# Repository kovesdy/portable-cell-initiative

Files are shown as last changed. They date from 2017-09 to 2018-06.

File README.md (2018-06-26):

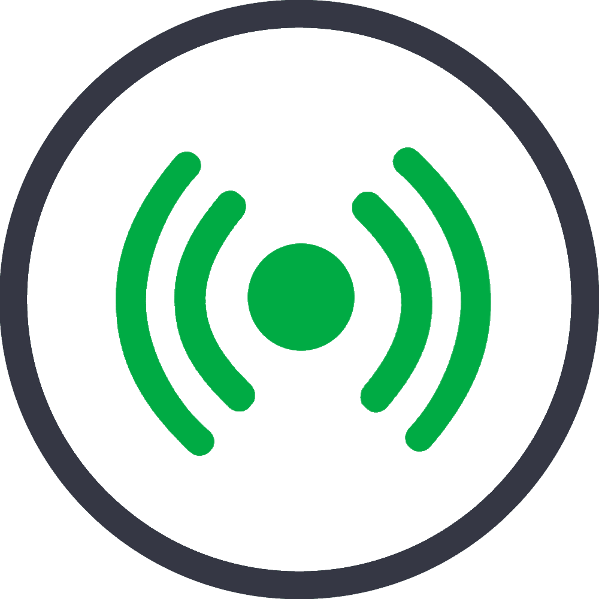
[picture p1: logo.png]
PCI Logo


# Portable Cell Initiative
An open-source software and hardware project to build portable micro-cells for deployment in disaster areas where power, internet, and infrastructure is destroyed.

After several hurricanes earlier this year, Puerto Rico, Houston, and other areas in the United States remain devastated. During and after such tragedies entire communities are left without critical resources, including any way to contact the outside world. Cellular service, a system taken for granted in everyday life, becomes a crucial tool for calling for emergencies, coordinating responses, directing aid, and contacting loved ones. Even regularly working cellular networks can collapse, as when cellular networks were overloaded and temporary paralyzed after the Boston marathon bombing. After natural catastrophes so severe that power lines and cell towers are destroyed, locals may be unable to request assistance, contact family members and friends, and coordinate rebuilding efforts while emergency workers become effectively stranded and unable to communicate for long periods of time.

The “Portable Cell Initiative”, tackles the challenge by developing a small, portable, and light system that acts as a temporary cell tower. These small units, called "microcells" can create a resilient network and be set up with no experience (plug-and-play).

## Features
* Connects to mobile devices through 2G protocol and allows calling, SMS, Internet connection without new SIM cards
* Easy-to-use web portal for mobile users links emergency responders and provides critical information include maps and emergency updates
* Connected to existing satellite constellation infrastructure
* Works anywhere on the planet with no re-configuration
* No dependance on existing infrastructure or power
* Can survive harsh temperature and weather conditions
* Can interconnect with other nearby microcells to create a larger network
* Flexible design
* Cheap and based on open-sourced hardware and software

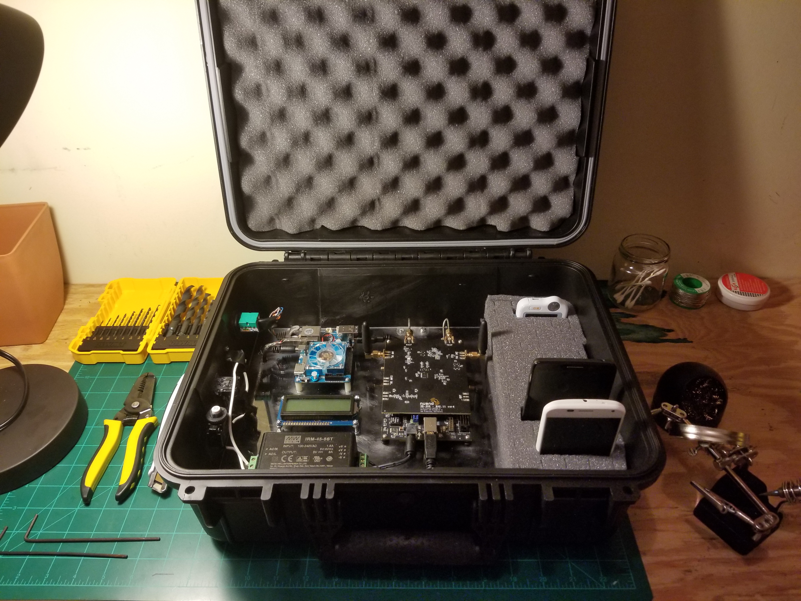
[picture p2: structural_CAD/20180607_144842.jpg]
Beamlink Revision 2 Prototype


## More information

#### [Complete Project Proposal](https://github.com/Ironarcher/portable-cell-initiative/blob/master/documentation/Project%20Proposal.pdf)

### Design and Technical Documents and Schematics
* [CAD Drawings](https://github.com/Ironarcher/portable-cell-initiative/tree/master/structural_CAD)
* [Networking Diagram](https://drive.google.com/file/d/1F7UjbKQFGlt_Ugc90fcQds3FkP_MWMTc/view?usp=sharing)
* [Safety Recommendations](https://github.com/Ironarcher/portable-cell-initiative/raw/master/documentation/Safety%20Recommendations.docx)
* [Properties of the Recommended Antenna](https://github.com/Ironarcher/portable-cell-initiative/raw/master/documentation/Antenna%20Analysis.docx)
* [Circuit Diagram](https://drive.google.com/file/d/19UB1lHhNbGaFvCO_THeIRcXM_tuGDZBh/view?usp=sharing)
* [Antenna Range and Estimation of user capacity](https://github.com/Ironarcher/portable-cell-initiative/raw/master/documentation/Range%20and%20Subscriber%20Analysis.docx)

### Software Development
The Software-defined Radio utilizes OpenBTS and YateBTS to process GSM signals.

The Linux server uses a custom configuration of Ubuntu 14 (Odroid XU4 compatible release). Visit the software page for a README with installation instructions.

#### Additional features available

- Set up instructions to enable config GUI web page and operation with BladeRF radios
- Custom YateBTS configuration files and scripts for disaster relief use
- Firewall configurations to limit idle network usage and connect to the master server
- Integration with Flowroute and its API for international calling
- GPRS configuration for enabling data service
- Automatic phone number assignment to users
- Informational display code (for use with USB serial displays)
- Code for network testing, temperature testing, other procedures

#### Captive Portal
-The Captive Portal technology, a lightweight web application that opens when users first connect to the cell tower, provides quick information to users and a twitter feed of curated information about the situation. This is part of our strategy to reduce network congestion and limit over-use of backhaul resources. Users can always opt to leave the page and access the Internet, returning to the page at any time.

[Find the code and contribute](https://github.com/Ironarcher/beamlink_captiveportal)

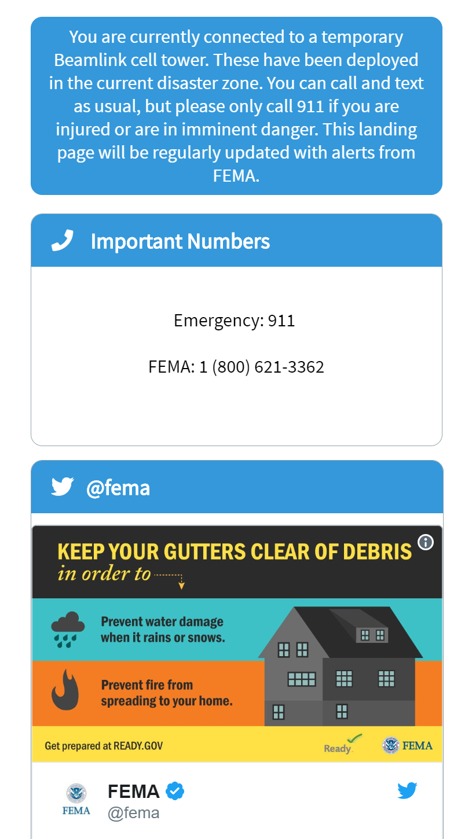
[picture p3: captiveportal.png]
Captive Portal example image


#### In Progress:
- VPN Setup guide between master server and cellular base stations
- Integration with Flowroute SMS API for international texting
- Automatic Flowroute number purchase and number management with OpenBTS
- Switching from GPRS to UMTS data service (3G) based on OpenBTS's UMTS package
- Release of multi-tower communication architecture
- RRLP tracking to allow first responders to locate people in emergency situations based on their cell phone's position (cellular triangulation) - Part of emergency calling as well
- E911 integration (for users to connect to the correct 911 operator in their area)
- Maia: A web service that provides a bird-eye view of our cellular towers connected together, laid on top of Google Maps. View each cell tower's location in proximity to others, and configure their network settings on-the-fly. Have direct access to each tower through built-in SSH capability. Create zones and divide frequencies to reduce cross-tower interference and manage handover settings. Edit automatic phone number systems and receive notifications if the tower malfunctions. Live readouts of pertinent information like core temperatures, number of active connections, new registrations, CPU usage, frequency congestion information, and more.

### Competitions and Challenges
[Mozilla and the National Science Foundation's Wireless Innovation for a Networked Society (Off the Grid Challenge)](https://wirelesschallenge.mozilla.org/#winners) - Honorable Mention

[USC Min Family Social Entrepreneurship Challenge 2017](http://viterbiundergrad.usc.edu/min/) - Finalist

- [People before Profits - USC Viterbi Magazine](https://magazine.viterbi.usc.edu/spring-2018/student-life/people-before-profits/)

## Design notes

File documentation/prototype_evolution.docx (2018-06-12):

Beamlink Prototype Evolution

Beamlink I

A power-efficient, yet powerful single board computer utilizes the newest mobile processors to create an independent cell tower.

The computer can assign phone numbers, store texts, link international calls, host a local web server, and even be remotely monitored and configured.

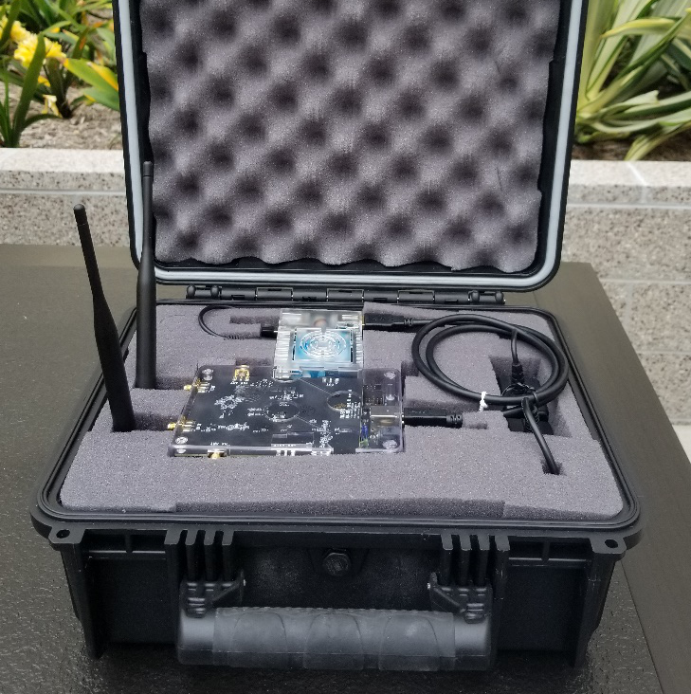
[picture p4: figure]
A picture containing wall, electronics Description generated with high confidence

Integrated battery allows for 7 hours of operation before connecting to outside power.

A water-proof case allows the cell tower to survive even when fully immersed in water. Foam padding and the reinforced case mean that the tower can survive being dropped. And weighing in at 8 pounds, the tower can truly be taken anywhere.

A software-defined radio allows use of any radio protocol, including GSM, Wi-Fi, and even LTE. The system can be instantly configured to meet the regulatory requirements of any country.

Beamlink II

Custom ports allow ethernet and power connections from the outside while keeping out water, while a switch provides more control over the device.

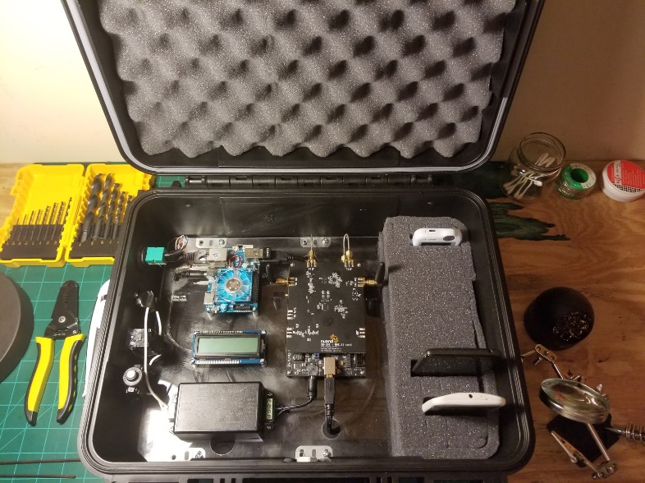
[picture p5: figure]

Built-in antennas and smaller coaxial cables allow for the case to operate while closed, even when an amplifier is attached.

The larger case has space for storing extra, pre-configured phones and medical devices. And the device is even lighter, at 7.5 pounds.

A custom power supply further reduces power consumption to 11.2-11.9 W during cell tower operation.

The information display reads out real-time information, such as the tower’s status, registered phones, and active connections.

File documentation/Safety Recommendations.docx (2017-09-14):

Portable Cell Initiative

Safety Considerations for Microcells

By: Arpad Kovesdy

Radiation and Antenna Safety

1. Electromagnetic radiation emitted by cellular phones and the base station antenna is considered nonionizing radiation: which means that the radiation’s energy is too low to ionize atoms. There are still dangers to using radio equipment, such as thermal effects. These thermal effects can cause injuries because electromagnetic radiation can heat body tissue, especially close to resonant body frequencies, which include 35 MHz, 70 MHz, and 400 MHz for adults, and additional resonances near 700 MHz and 1 GHz.
2. There is some research to suggest a link between biological effects and exposure to radiation. However, there is no demonstrated correlation that “low-level EMR causes adverse health effects”.
3. “The IEEE guidelines excludes any transmitter with an output below 7W because such low-power transmitters would not be able to produce significant whole-body heating”. However, there is concern that certain power densities may be more than standards when considering small transmitters place near the head.

General Guidelines

I. No person should ever be next to a transmitted antenna while it is being powered. Never transmit above 25W in a VHF radio mobile installation without measuring the RF fields emitted in the surrounding area.
II. When using transmitters that transmit above 1 kW of power, ensure that directional antennas are raised 35 feet above inhabited areas.
III. Never work on or touch an RF antenna when power is applied.

Antenna Grounding

1. Only certain types of antennas require grounding[^1], which include ones that require current flow to the ground to complete a circuit. For example, a quarter-wave vertical is one antenna that requires one wire to connect from the feedline to the base of the antenna and one wire that connects to ground.
2. All other antennas do not require a direct connection to ground. These include dipole antennas or ground plane antennas.
3. “Common-mode currents” must be kept off of the feedline through the use of a “current or choke balun”.

General Guidelines

I. Per the specified recommendations to use a half-wave dipole or similar variant with a ground plane, a current or choke balun must be attached.
II. A direct connection to RF ground is not required if using a half-wave dipole or similar variant with a ground plane.

Electrical Grounding

Generator Safety

I. Stay at least 24 inches away from power supply, linear generators, transformers, electrical fans, and other sources or drains of AC power when power is applied to avoid exposure to high-level 60 Hz magnetic fields.

Additional Safe Practices

Reference: The 1997 ARRL Handbook for Radio Amateurs © 1996 American Radio Relay League, Inc. (available for reproduction for noncommercial use, provided credit is given)

[^1] http://www.arrl.org/grounding

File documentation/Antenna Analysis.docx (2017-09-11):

Portable Cell Initiative

Antenna Analysis for Microcells

By: Arpad Kovesdy

Summary

The antenna’s design, provided a 30 m elevation from a real ground, provides an isotropic gain that varies from 6.48 dBi for the downlink antenna to 7.25 dBi for the uplink antenna based on computer models in 4nec2 (a computer program). Radiation patterns modeled support the antenna theory of horizontal omnidirectionality, even in different environments. The antennae standing wave ratios are at a manageable value of 1.18 based on the average operating frequency used and a 50 Ω coaxial cable feed line. Other factors such as feed line attenuation are also explored further.

Basic Antenna Configuration

The microcell’s base station for GSM communications consists of two antennas: one for uplink (handling radio communications the mobile user to the microcell) and one for downlink (microcell to the mobile users). For both antennae, there are two portions: a conducting and a grounding region. In a classic half-wave dipole antenna that is pointing vertically and is thus vertically polarized, the feed point will be at the middle of two conductors pointing towards the ground and towards the sky. The vertical polarization is common in mobile systems because “vertical polarization has somewhat lower attenuation over terrain”[^1].The radiation pattern of this type of antenna is a donut shape that projects most of the radiation perpendicular to the conductor. To lower the impedance to the characteristic impedance of the feed line (which is 50 Ω), from the antenna impedance of a dipole, the grounding portion is raised closer to be 30° below the horizontal. In total, there are three conductors that point out from the center to form the grounding portion to improve omnidirectionality. Here is an image of the projected geometry with wires in gray and axes in green:

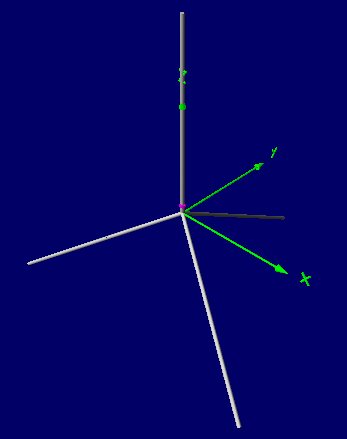
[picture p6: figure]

Antenna Characteristics
The length of the antenna conductors (which is around a quarter of the wavelength of the transmitted or received radio wave since the complete system is based on a half-wave dipole design) is given by the following equation[^2]:

Monopole Length (feet)=234/(Frequency (MHz))

The following characteristics of the antennae were calculated based on simulations in 4nec2, a program for showing how EM radiation is generated by different antenna geometries. The same simulations were also conducted over a 30 m real ground, which offers more realism than the simulation of the antennae in free space (an environment that does not practically exist). The diameter of the wires used in the antennae is 0.81 mm, which is the same size as the core of a common 50 Ω coaxial cable (RG-58 U). The following tables show the various characteristics that were computed using the computer models:

Characteristic | Value
Transmission frequency range | 890 – 915 MHz
Average operating frequency | 902.5 MHz
Wavelength | 0.332 m
Monopole length | 0.07903 m
Number of monopoles | 4
Isotropic Gain in Free Space | 1.77 dBi
Isotropic Gain above a 30 m real ground | 7.25 dBi
Relative Directivity Factor | 9.67
Impedance | 44.1 Ω
Radiated Efficiency (30 m above real ground) | 59.47 %
S.W.R. (50 Ω feed line) | 1.18

Table 1: Uplink Antenna Characteristics

Characteristic | Value
Transmission frequency range | 930 – 960 MHz
Average operating frequency | 945 MHz
Wavelength | 0.317 m
Monopole length | 0.0755 m
Number of monopoles | 4
Isotropic Gain in Free Space | 1.77 dBi
Isotropic Gain above a 30 m real ground | 6.48 dBi
Relative Directivity Factor | 8.74
Impedance | 44.3 Ω
Radiated Efficiency (30 m above real ground) | 59.43%
S.W.R. (50 Ω feed line) | 1.18

Table 2: Downlink Antenna Characteristics

The following images depict the radiation patterns of the uplink antenna (which are very similar for the downlink antenna) in different environments. There are 3D plots which show the area around the antenna and 2D plots which show the patterns from a vertical and horizontal aspect. The first two images are in free space and the second two are when the antenna is 30 m above real ground.

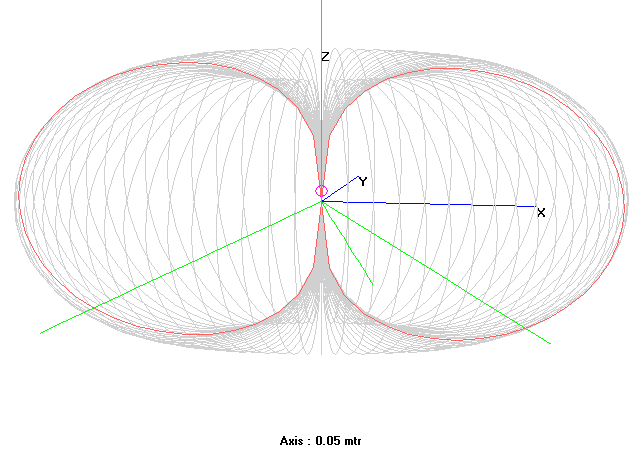
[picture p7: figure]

Image 2: Radiation Pattern (Uplink) in free space

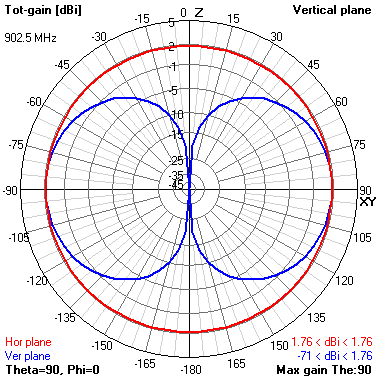
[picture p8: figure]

Image 3: Radiation pattern (uplink) from the vertical plane’s perspective in free space

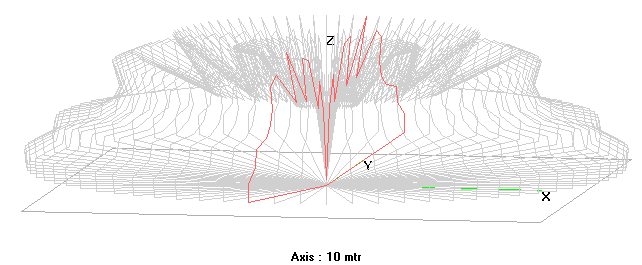
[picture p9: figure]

Image 4: Radiation pattern (uplink) when the antenna is 30 m above real ground

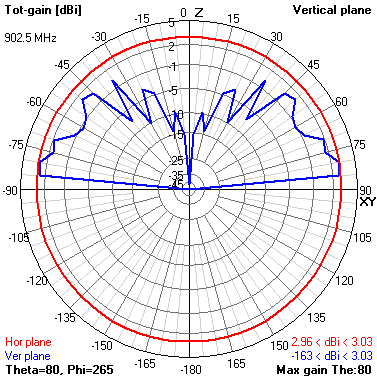
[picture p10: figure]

Image 4: Radiation pattern (uplink) from the vertical plane’s perspective when the antenna is 30 m above real ground

Characteristic | Value
Dielectric Constant | 13
Conductivity | 5.0 x 10⁻³ Mhos/meter

Table 3: Real ground properties (average)

Other Considerations

When constructing the tower upon which to mount the uplink and downlink antennae, it is important that any conducting materials, like guy wires, extra cables, and metal supports, should be separated from the antennae to prevent electromagnetic interference. Additionally, the antennae should be separated by several wavelengths to reduce interference further, since the two antennae transmit or receive on similar frequencies.

It is therefore highly recommended that the antenna and antenna tower be mounted on an elevated building to reduce the necessary support required. Additionally, there will also be a loss in gain (nominal attenuation) in the coaxial cable that connects the amplifier to the antenna. This is equivalent to around 13 to 16 dB/100 feet of coaxial cable in frequencies around 1000 MHz[^3]. It is recommended that this cable be as short as possible.

Overall, the antenna gain varies dramatically based on the surface under the antenna and the elevation. The characteristics also depend on the environment (buildings, hill, etc.) and tower configuration (conductors, cable lengths, etc.) that surround the antenna. The simulation showed an antenna gain of 1.77 to 6.5/7.3 dBi based on different environments. In further calculations, we will continue to reference the standard value of 2.16 for monopole antenna systems with virtual grounds as a “worst case scenario”

[^1] http://people.csail.mit.edu/bkph/cellular_repeater_outside.shtml
[^2] Silver, H. W. (2007). The ARRL general class license manual. Newington, CT: ARRL.
[^3] www.prioritywire.com/specs/c-3.pdf

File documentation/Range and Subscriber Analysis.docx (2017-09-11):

Portable Cell Initiative

Range and Subscriber Capability Analysis for Microcells

By: Arpad Kovesdy

Summary

The estimated range of a microcell, with an antenna that is 30 m from the ground and which is operating on the 900 MHz GSM frequency, is around 4 km and may server an estimated 3340 subscribers in the surrounding area when utilizing the recommended hardware.

Range Analysis

To find the range of the base station to subscribing users, one must calculate how the radio signals propagate between the base station antenna and the mobile device. There are two connections during cellular service, a downlink and an uplink. In each case, the radio transmission (either from the base station to the mobile device or vice versa) must be strong enough to overcome the background electromagnetic radiation, known as “noise”. These transmitted power quantities will determine the range of the microcell.

The fundamental way to determine the range of an antenna is for the radio transmitter to transmit at a high enough power, PT, to overcome the free space propagation loss and noise that is fundamental to the travel of electromagnetic waves from a source to the receiver.

The power transmitted by the base station antenna depends on both the software-defined radio and the amplifier. The bladeRF x40, the recommended SDR in this project, can generate +6 dBm of TX power[^1] and its amplifier can provide a maximum +31 dBm of amplification[^2]. Together, the system provides +37 dBm of transmission power, equivalent to 5.01W.

The power transmitted by a GSM cell phone depends significantly on the model and the settings of the device, which adjust the power to optimize battery life. The GSM system controls the phone’s transmission power through signals sent by the base station to optimize the link from the mobile device back to the base station. This way, the mobile device will conserve battery life while overcoming the noise of the surrounding area. GSM900 standards dictates that the peak mobile TX power (Cellular Radio, 203)[^3] should be 20W (+43 dBm) at the Class 1 power setting (with incremental classes every 2 or 4 dBm). Since the GSM cell phone is capable of higher transmission power than the base station and the base station has a low noise amplifier that can boost signals up to 20 dB from the mobile device, PT will be considered at the base station transmission power of +37 dBm.

According to Cellular Radio (p.44), the equation for determining the power is by weighing the effects of the signal to noise ratio S/N required for the signal to be processed, the effective noise threshold NR, the free space propagation loss factor L, the gain from the transmitter (GT) and receiver (GR) due to amplification or antenna gain, and building penetration loss (BPL) from radio signals entering through structures to reach mobile devices. If these factors are considered, then any transmission power above this threshold allows radio communications:

P_T >(S/N)+N_R +L-G_T -G_R (dBm)+BPL

If the power transmitted can overcome these factors, then successful GSM communications may be transmitted. In this equation, the receiver noise threshold is a measure of the ambient and spurious electromagnetic radiation that interferes with the radio signal. In this formula, the effective noise temperature is assumed to be around the reference temperature of 270K, which is near suburban noise levels at 900 MHz (Cellular Radio, 45). The equation also factors in the bandwidth which GSM occupies, which is 180 kHz per channel[^4]:

N_R =-174 dB+10log(180,000 Hz Receiver Bandwidth for GSM)= -121.4 dB

Several of the inputs may vary in different environments, but here is a simulation of the mobile device receiving signals from the base station transmitter:

Variable | Value | Description
S/N | +9.5 dB | 9 dB is described as the worst-case baseband S/N ratio, and an implementation margin of 0.5 to 2 dB[^5] is typically added
NR | -121.4 dBm | From the above equation for receiver noise threshold in GSM systems
GT | +2.16 dB | Monopole antenna with a virtual ground will have a worst-case gain of approximately a dipole antenna. However, the maximum gain could be up to 6.48 dB*.
GR | 0 dB | Assume that the cell phone antenna is omnidirectional and isotropic
BPL | 10 dB | Conservative estimate: BPL ranges from 10-20 dB (Cellular Radio, 56)

Table 1: Values for the PT required for base station communication (downlink) with a mobile station

*See antenna analysis for this estimate and other considerations that may affect this value

+37 dBm=+9.5 dB-121.4 dBm+L_(max) -2.16 dB+0 dB+10 dB

L_(max) =141.1 dB

Now that the Lmax has been determined as the most the radio signal may fade before transmission no longer functions, relationships may be calculated between the free space propagation loss L and distance d between the source and receiver and the wavelength of the radio wave (Cellular Radio, p.44)

L = ((4πd)/λ)^2

However, interference occurs due terrain and obstacles between the transmitter and receiver because radio waves reflect off these surfaces and occasionally combine to cancel out the signal. These multipath interferences can have been experimentally modeled for different urban and suburban environments by Okumara in 1986 and formulated by Hata in 1980[^6]. This equation provides the free space propagation loss factor and is based on urban area losses in medium and small cities from ground reflections, buildings, and elevation changes (Mobile Communications, p.25):

L_p =69.55+26.16log_10 f_c -13.82log_10 h_b -a(h_m )+(44.9-6.55log_10 h_b )log_10 R

a(h_m )=(1.1log_10 f_c -0.7)h_m -(1.56log_10 f_c -0.8)

Where fc is the frequency between 150 and 1500 MHz, hb is the height of the base station antenna between 30 and 200 m, hm is the height of the mobile antenna (how high the cell phone is from the ground) between 1 and 10 m, and R is the distance between base station and antenna between 1 and 20 km. In this simulation, these variables were used:

Frequency | 900 MHz
Height of mobile antenna | 1 m
Height of base station antenna | 30 m

Table 2: Parameters of the range analysis calculations

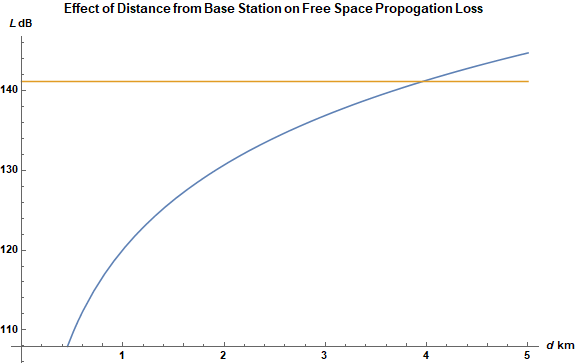
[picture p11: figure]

R_(max) =3.96 km ≈4 km

Additionally, an operator of a microcell might want a higher antenna height, if possible, to improve the signal and increase Rmax. The following graph shows this relationship as the free space propagation loss at 1 km distance from the cell, assuming the same 1 m mobile antenna height and 900 MHz frequency as before:

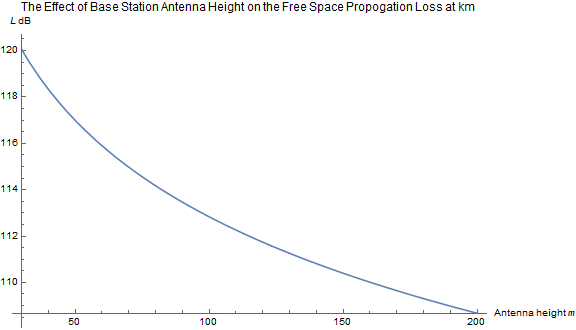
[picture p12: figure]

Antenna Height (m) | Maximum Range (km)
30 | 3.96
40 | 4.59
50 | 5.17
60 | 5.73
70 | 6.25
80 | 6.76
90 | 7.26
100 | 7.74

Table 3: Maximum cell range based on antenna height for reference

Subscriber Capacity

To calculate how many subscribing mobile devices a cell may support, one may use the general equation (Cellular radio, 254):

Subscribers per cell (BS)= (Number of channels available)/(Subscriber Erlang rate)

The number of channels available for a GSM system is heavily dependent on the version and frequency utilized, and may be dynamic based on these factors. The GSM system recommended for worldwide compatibility is centered on the 900 MHz band, but other bands may be utilized to reduce congestion from nearby cell towers. Lower frequencies also “improve coverage with lower power”[^7] The band is divided into radio “carriers” or channels used for communications, which range from 925 to 960 MHz for downlink and 880 to 915 MHz for uplink (Cellular radio, 191). Within these ranges, there is a maximum of 125 channels (CR, 191), which allow 8 slots per channel per the TDMA technology[^8]. Overall, a GSM system can support up to 1000 voice channels if needed (Tipper).

The number of actual channels utilized heavily depends on the computing power of the Linux server that is processing information. The largest bottlenecks for GSM processing include the throughput of the USB connection between the software-defined radio and the Linux server and the processing power of the Linux server. Major in CPUs and new USB3.0 standards have greatly decreased the costs and complexity of equipment required to support GSM communications. Based on previous research of the computing requirements[^9], the following performance statistics are estimated, but must be experimentally verified:

SpecFP92 metric/logical channel (Turletti, Tennenhouse) | 30 (min) to 51 (max)
Computing power required per logical channel (MWIPS) | 36.3 (min) to 61.7 (max)
Raspberry Pi 3.0 B computing performance (MWIPS) | 1113
Odroid-XU4 computing performance (MWIPS) | 6186.3
GSM maximum throughput per channel | 284.33 kbps
USB2.0 throughout performance* | 26.2 MB/second
USB3.0 throughoutput performance* | 258 MB/second
Raspberry Pi 3.0 B channel support** | 18
Odroid-XU4 channel support** | 100

Table 4: Performance requirements for GSM based on Linux server options. Computing power per channel is based on the SpecFP92 benchmark and server hardware is tested with Whetstone double precision benchmark (x3)[^10].

*Measure on the Odroid-XU4 Linux server which was connected to an SSD (write speed results displayed which are similar, but slower to read speeds)

**Theoretical values that have not been tested in deployed environments with interference

The connection between the radio and Linux server does not represent a bottleneck for GSM data, as even with each channel transmitting 284.33 Kbps of throughput, USB2.0 has the capability of supporting up to 738 voice channels if required. USB3.0, which is recommended, can support nearly 10 times the channel data throughput, which is well above the 1000 voice channel capacity.

The main bottleneck is instead, the processing power (which is measured in how many floating-point operations each Linux server can complete per second). The results are shown in Table 3 based on the computing power bottleneck and the calculations are explained in the appendix. Overall, the recommended Linux server can handle 100 voice channels at once.

The “Subscriber Erlang rate” describes the amount of time each subscriber uses the network for calling or data operations. The unit of Erlang may be defined as the “average number of calls in progress simultaneously during the period of one hour” (Cellular Radio, 251). The actual calling rate of subscribers is typically six calls a day of 150 second duration (Cellular Radio, 253). To calculate this, use the equation on p.253:

Calling rate= (No. calls*Call duration (sec))/(60*60*24 hours a day)=(6*150)/(60*60*24)=0.0104 Erlangs

According to Cellular Radio, the most traffic will be concentrated in a “busy hour” (Cellular Radio, 253), where the calling rate increases to a maximum of 0.03 Erlangs. Now, assuming a grade of service of 0.01 (1/100 calls are delayed or blocked), the subscribers may be calculated (Cellular Radio, 254) with an Odroid-XU4 server as:

Subscribers=(100 channels available)/(Subscriber Erlang rate=0.03)=3340 users per cell

Appendix:

The calculations in table 1 to determine the computing power required per logical channel in MIPS was done by first ascertaining the SPECFP92 score required per logical channel:

SPECFP92 per logical channel = 30 (min) to 51 (max).

For the DEC 3000/900 AXP workstation, the same Turletti, Tennenhouse article states that the SPECFP92 performance is: 187.6.

The Whetstone performance in MWIPS (millions of whetstone instructions per second), but in double-precision mode of the DEC 3000/900, is 227[^11].

Therefore, each logical channel Whetstone score in MWIPS = 36.3 (min) to 61.7 (max)

From the Whetstone (x3) double precision benchmark run by Hardkernel, the raspberry pi 3 has a score of 1113 MWIPS and the Odroid-XU4 has a score of 6186.3

The number of channels supported by each Linux server can therefore be determined by dividing the Whetstone performance of each server device by the maximum (worst-case scenario) amount of computing power in MWIPS to operate each voice/logical channel.

Note that both the whetstone and SPECFP92 benchmarks measure the amount of floating-point operations that the computer can handle and are therefore open to correlation.

Each logical channel is a voice channel (a radio carrier is a 200 kHz band that allows data to be sent in “bursts” via time division multiple access, which allows 8 users to have logical, or voice channels per radio carrier)

[^1] https://www.nuand.com/blog/product/bladerf-x40/
[^2] https://www.nuand.com/blog/product/amplifier/
[^3] Macario, R. C. (1997). Cellular radio: principles and design (2nd ed.). New York: McGraw-Hill, 44.
[^4] http://inf-server.inf.uth.gr/courses/CE433/tutorials/GSM%20Transceiver.pdf and http://mobiledevdesign.com/learning-resources/introduction-gsm-and-gsm-mobile-rf-transceiver-derivation
[^5] http://mobiledevdesign.com/learning-resources/introduction-gsm-and-gsm-mobile-rf-transceiver-derivation
[^6] Sasaoka, H. (2000). Mobile Communications. Tokyo: Ohmsha, 25.
[^7] Iedema, M. (2015). Getting started with OpenBTS: build open source mobile networks (1st ed.). Sebastopol, CA: OReilly.
[^8] Tipper, D. (n.d.). Global System for Mobile. Lecture presented at Telecom 2720 in University of Pittsburg. Retrieved from http://www.pitt.edu/~dtipper/2720/2720_Slides8.pdf
[^9] Turletti, T., & Tennenhouse, D. (1997). Estimating the computational requirements of a software GSM base station. Proceedings of ICC97 - International Conference on Communications. doi:10.1109/icc.1997.605186
[^10] http://www.hardkernel.com/main/products/prdt_info.php
[^11] http://www.roylongbottom.org.uk/whetstone.htm

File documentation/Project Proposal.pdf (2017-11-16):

Published in November 2017 | | Website and Documentation (https://github.com/Ironarcher/portable-cell-initiative)
Portable | Cell | Initiative

## Project Proposal

Submitted for the

Wireless Innovation for a Networked Society Challenge by Mozilla and the National Science Foundation
Off-the-Grid Internet Challenge

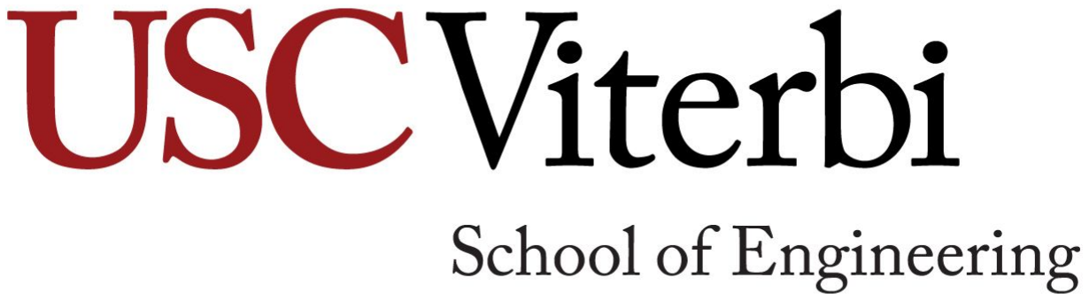
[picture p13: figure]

USC Min Family Social Entrepreneurship Challenge 2017

Project Proposal is subject to the Mozilla Public License 2.0 (https://choosealicense.com/licenses/mpl-2.0/)

P O R T A B L E C E L L I N I T I A I V E

## OVERVIEW

After several hurricanes earlier this year, Puerto Rico, Houston, and other areas in the United States remain devastated. During and after such tragedies entire communities are left without critical resources, including any way to contact the outside world. Cellular service, a system taken for granted in everyday life, becomes a crucial tool for calling for emergencies, coordinating responses, directing aid, and contacting loved ones. Even regularly working cellular networks can collapse, such as when mobile systems overloaded and became temporarily paralyzed after the Boston marathon bombing. (https://www.bostonglobe.com/business/2013/04/16/cellphone-networks-overwhelmed-blast-aftermath/wq7AX6AvnEemM35XTH152K/story.html) After natural catastrophes so severe that power lines and cell towers are destroyed, locals may be unable to request assistance, contact family members and friends, and coordinate rebuilding efforts while emergency workers become effectively stranded and unable to communicate for long periods of time.

After Hurricane Maria struck Puerto Rico, the Economist reported that “the lack of electricity and communication set off a chain reaction that hindered the entire disaster-response effort, complicating everything from delivering food to burying bodies.” Weeks after the disaster, only 5% of the power grid and 20% of phone towers have been repaired. Cars pile up on the shoulders of roads near phone towers to use their phones before entering more rural areas. A decentralized solution is required to connect communities to the outside world even without power or Internet connectivity.

The solution named the “Portable Cell Initiative” tackles the challenge by developing a small, portable, and light system that acts as a temporary cell tower. Using many, smaller units called “microcells” can allow a quick emergency response that creates a resilient network by linking up to adjacent microcells. The PCI cellular tower can be set up quickly by anyone, even those with little technical experience. The cell tower connects to mobile devices through 2G protocols without the need for new SIM cards. The tower allows users to send SMS and call other users in the network, access the internet freely, and instantly receive critical information including maps and emergency updates. The tower will connect to external networks and the internet through a satellite connection which will enable the solution to be deployed anywhere around the globe without any other infrastructure available. The cell towers may be interconnected to create an entire cellular network that is entirely independent of existing power and mobile networks.

The proposal includes diagrams, flowcharts, cost estimates, software and hardware details, milestones, and information about the team that will build the solution.

## GOALS

1. Design and build a cellular radio antenna that can send and receive signals over GSM frequencies within a radius of one mile from the cellular tower.
a. The tower’s construction should be:
i. Modular in design,
ii. | Easy to set up without prior technical experience or system knowledge,
iii. | Versatile enough to deploy in any non-polar environment.
2. Design and model the use of commercial off-the-shelf and open source hardware components to:
a. Generate radio signals using a software-defined radio (SDR),
b. Process information, including cell signals and requests through a server,
c. Amplify signals from the SDR to the radio antenna, and
d. Provide power in a portable and mobile manner.
3. Create software for the processing equipment to:
a. Allow SMS and Calling between users connected to the tower,
b. Allow any user to connect via 2G GSM protocols without the need of a separate SIM card other than one for a standard GSM carrier,
i. And authenticate, monitor, and potentially throttle mobile access to
| maintain network stability,
c. Allow free access to the internet without limits on which websites users may visit,
d. Provide a landing page (which is known as a “captive portal”) upon connecting via the cellular network or via WiFi that shows emergency updates, critical information, and maps quickly to disaster victims, and
e. Allow cellular towers to connect to other towers of the same model to expand the network to a greater area.

## USE

## Users

Emergency responders may utilize the network to communicate rescue efforts and coordinate aid provision to disaster victims. Governments and other organizations may provide emergency information and instantaneous updates to disaster areas through the landing page and internet access. Disaster victims may also utilize the networks to check in with families and friends and access social media networks or any other necessary applications through the Internet. 3340 subscribers may be supported at most, assuming each subscriber makes six 90-second calls each day.

## Location

The proposed solution is capable of operating globally as the global satellite network provides internet access anywhere in the world. The rugged construction of the base station will allow use in both hot and cold environments and must withstand local weather such as rain or snow. The cellular radio antenna may be stuck in the ground outside and tethered to withstand wind and extreme weather conditions. Alternatively, the tower can be placed on top of high buildings to provide additional range.

## OPEN SOURCED

Inside this document, there are sometimes different options for how to construct these microcells, because as long as the software and algorithms controlling the microcells are the same, the cell towers can be built using a variety of materials, with different types of antennae, different server hardware, and different tower heights. The beauty of open sourced hardware and software is that any member of the international community can adapt the project to their environment, experiment freely, and share improvements with other members and the creators of the project. This project uses the Mozilla Public License 2.0 (https://choosealicense.com/licenses/mpl-2.0/) which provides the public with conditional permission to freely use this project commercially and distribute and modify this project.

## HARDWARE ARCHITECTURE

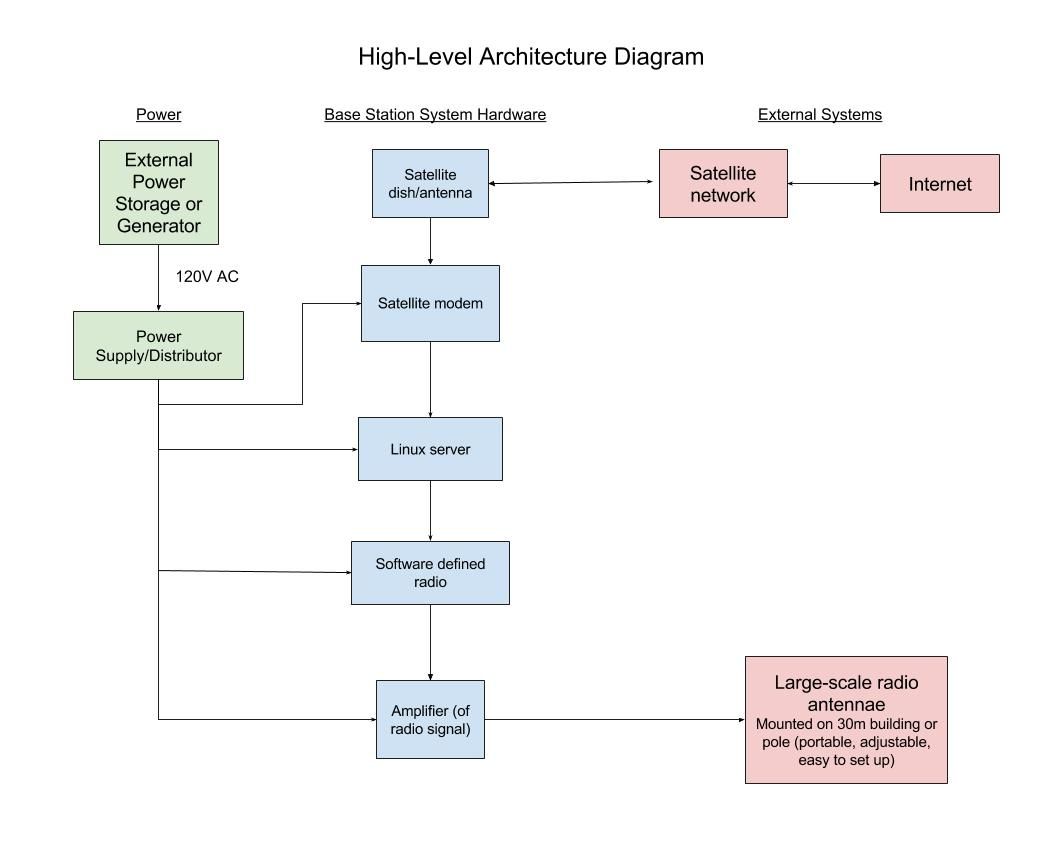
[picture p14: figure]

The goal of the cell tower is to send and receive radio signals as a “cell tower” and provide calls, SMS, and internet services for mobile devices in its range. The first component in the hardware is the radio antenna, which transmits and receives radio signals through the “GSM protocol” between the cell tower and mobile devices. The antenna connects to the radio amplifier, which increases the range of the cell tower by boosting the amplitude of the radio signal. This amplifier also picks up faint signals from mobile phones far away.

Note: GSM stands for “Global System for Mobile Communications” and represents a widely used standard in mobile cellular networks that is known as 2G. 3G, or third generations systems often use a standard called UMTS, which was based on the original GSM standard.

The amplifier then connects to the base station, which is the “brains” of the cell tower by processing the radio signals that are sent and received. This is made up of two components: the software-defined radio and the Linux server, which is a small, programmable computer that directs the activity on the cellular network and processes calls, messages, and web requests.

Finally, the Linux server connects to the satellite modem, which interfaces with a satellite dish or antenna to communicate with a satellite to provide internet access to the base station. Altogether, the very low-power system may be powered by a portable battery for a limited time and may connect to small solar panels or a portable diesel generator.

## Radio Antenna

An antenna is simply a conductor, like a rod or wire, that converts the electrical energy sent from the radio transmitter into radio waves. Alternatively, a conductor can act as a receiving antenna by intercepting electromagnetic radiation and creating electrical currents that are sent to a radio receiver. The simplest antenna, pictured
here

1
is a “dipole antenna,” which consists of a quarter wavelength segment connected to the center conductor of a coaxial cable and another identical segment that is connected to the shield, which is grounded. The wavelength refers to the wavelength of
the radio wave emitted or received,
which varies based on the frequency

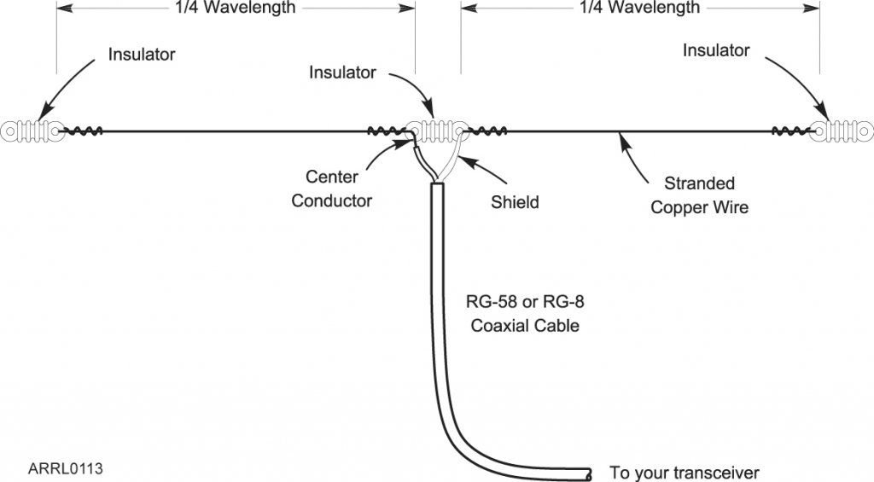
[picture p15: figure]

transmitted or received. A dipole antenna is useful for creating an omnidirectional radiation pattern around the antenna since radio waves are
generated and received from all directions perpendicular
to the conductor. For example, in this image, a dipole
antenna creates a donut-shaped radiation pattern. A typical issue with dipole antennae is that the impedance of the antenna is typically around 72Ω, yet this must be reduced to approximately 50Ω to match the impedance
used in the feed lines (coaxial cables) and the base
station. Matching impedance can significantly increase

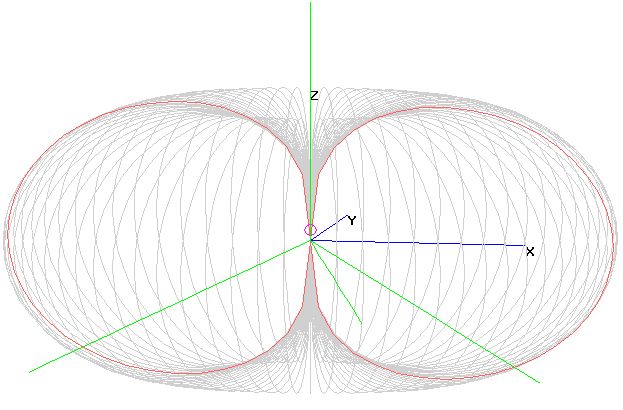
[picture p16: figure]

the power transfer and reduce the phenomenon of signal reflection. The grounding monopoles (which connects to the shield) can be tilted 30° from the parallel orientation with the resonant antenna to lower the effective impedance. This type of antenna incorporates four quarter-wave monopole antenna in a configuration to provide the correct impedance. In this example to the right

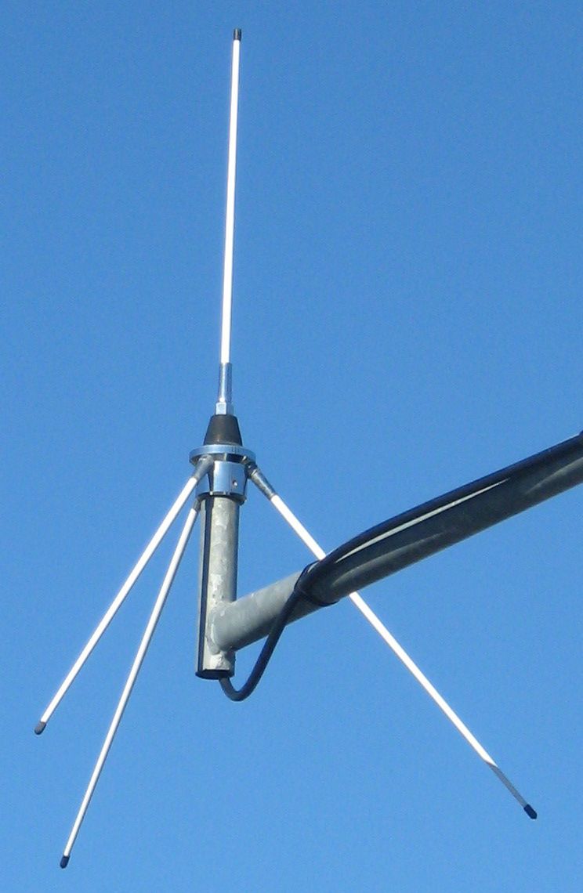
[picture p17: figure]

2
, a VHF antenna is
impedance matched to 50Ω while having an omnidirectional radiation pattern thanks to the three, downward-facing grounding antennae. Such an antenna is recommended for this project as the design has low antenna gain, excellent impedance matching, and is simple to construct.

The cell tower will consist of two quarter-wavelength monopole antennae: one to transmit and one to receive. The antennae will be surrounded by plastic shrouds to prevent moisture or weather damage. Any conducting materials, like guy wires, extra cables, and metal supports, should not be used to avoid electromagnetic interference. Additionally, the antennae should be separated by several wavelengths to reduce interference further. Here are some characteristics of the system, provided 30m elevation and based on normal communication across the 900 MHz GSM band:

Characteristic | Value
Uplink Antenna Length (Per monopole) | 7.9 cm
Downlink Antenna Length (Per monopole) | 7.55 cm
S.W.R (50 Ω feed line) | 1.18
Range | 4 km

The antenna feed line is a coaxial cable, most likely of type RG-58, with small enough diameter to fit into the antenna mast. The monopoles are made of conductive wire and connect to the coaxial cable at the center of the antenna structure. The coaxial cable’s ground sheath is split into three directions that plug into each of the three ground planes. The coaxial cable’s inner core wire (which brings the radio signal) is directed straight upwards and acts as the actively radiating monopole.

## Base Station

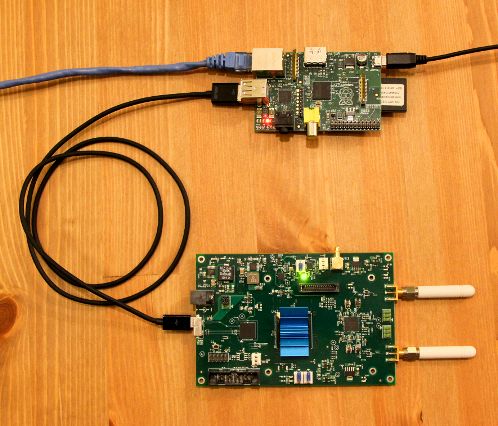
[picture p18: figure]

An simple base station example: A bladeRF connected to a Raspberry Pi. Source: Nuand.com

### Software-defined Radio

A software-defined radio is a device that transmits and receives wireless signals in the radio frequency spectrum and has all physical functions of said radio as software defined

3
. A recent
innovation, the software-defined radio allows programmability and incredible flexibility, as radio communications can be controlled purely through programs and without the need for any specific hardware. Recently, these innovations, many of which are open-sourced, have allowed for anyone, including hobbyists and professionals, to experiment cheaply with radio
communications.

One such open-source SDR is the bladeRF series of products built by Nuand. The bladeRF x40 is, for example, a transceiver that can tune from 300Mhz to 3.8Ghz and is perfect for use in “GSM and LTE picocells”

4
. The bladeRF x40 ($420) can interface via USB3.0 with servers, like in the image above. The system is also full-duplex, meaning that it can send and receive signals simultaneously.

Nuand’s own amplifier

5 can be connected to the sending and receiving connectors of the radio to amplify the radio signal. This particular amplifier contains both a low noise amplifier and a power amplifier. The presence of a low noise amplifier can improve the quality of weak signals received, which is critical for a cell tower that may receive many radio signals simultaneously with a high amount of noise. Furthermore, the power amplifier is capable of increasing the signal gain up to 33 dB in the 2.4 GHz band. Monitoring of the power output of the amplifier is available through the Linux server. Additionally, it is recommended that a dedicated power supply is connected to the amplifier to allow more power draw and thus greater amplification. The Nuand Power Supply

6
($15) can provide up to 15W and adapts power from common worldwide, AC sources.

### Linux Server

The Raspberry Pi is an excellent option for controlling a small cell site base station, because the single-board computer is cheap, mass-produced, and open-sourced. The newest iteration of the Raspberry Pi is the called the Pi 3 Model B and is available for $35 internationally. The lightweight and compact design only draws 1 to 4W of power

7 while still running a 1.2Ghz Broadcom chip with 1GB of RAM and WiFi and bluetooth support out of the box. Altogether, the Raspberry Pi can reliably run interface between the base station and satellite modem for long periods of time while producing little heat.

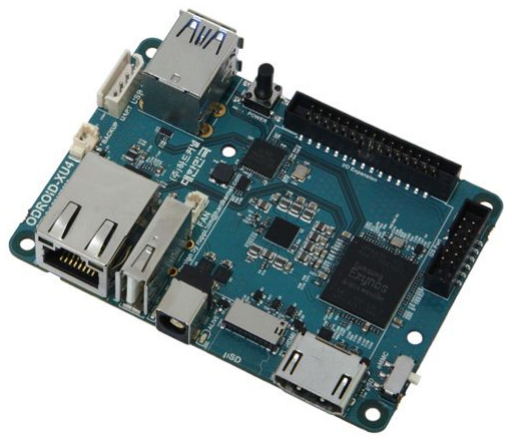
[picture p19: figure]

Another option is the Odroid XU-4 ($59), a more powerful alternative to the Raspberry Pi line of devices that includes greater processing power (with benchmark scores five to six times better than the

Raspberry Pi 3

8
) and therefore a capacity to handle much larger amounts of traffic as processing speeds scale cell tower capacity. Furthermore, even though the XU-4 has a similar form factor and size as the Raspberry Pi, it also includes USB 3.0 which is proven to be at least 10x faster than the USB 2.0 on the Pi. The Gigabit Ethernet port also reduces potential bottlenecks to the satellite modem. However, the basic XU-4 is more expensive and also does not support Wi-Fi and Bluetooth connections natively (they require adapters into the USB ports). Unfortunately, the project is not open source, although schematics are available to the public

9 and extensive
documentation and tutorials are available online, similar to the Raspberry Pi. This computer weighs 38 grams.

## Power

The power demanded by individual recommended components are as follows:

Component | Power draw idle | Power draw active | Power draw maximum
Raspberry Pi 3 10 | 1.4W | 2.4W | 5.1W
Odroid XU-4 11 | 4.2W | 13W | 20W
bladeRF x40 and Amplifier 12 | 2.3W | 9.0W | 15W
Explorer 510 (Satellite modem) 13 | 0.8W | 14W | 38W
Total* | 8.7W | 38.4W | 73W

*The total power draw is based on the recommended combination: Odroid XU-4, bladeRF, and Explorer 510
The power must be introduced from a portable generator, solar panel, or battery pack to the power bus on board the PCI system. The power bus accepts one 120V AC connection and distributes that power to the rest of the components, including servers, radios, modems, and antennae. These individual components each have individual converters to draw the correct voltage from the power bus.

It is recommended that the main power bus is connected to an intermediary battery pack that accepts DC power, has a fuse to prevent damage to the circuitry, and creates smooth AC power at the correct frequency. The DC power can then come from either a diesel generator that runs temporarily to charge up the battery or a solar panel that provides an average power delivery above the required power draw over a 24 hour period.

A large variety of components off-the-shelf and custom-made will perform well in this system. For the cost estimate, a Goal Zero battery pack (http://www.goalzero.com/p/476/goal-zero-yeti-1000-lithium-portable-power-station) was chosen with 1045 Watt-hours of capacity that is capable of producing 120V 60Hz AC power and also interface with Goal Zero solar panels, such as a briefcase model (http://www.goalzero.com/ecommerce/product.i?pid=428) that is capable of generating up to 100W of solar energy and storing it in the battery pack. A 1045 Watt-hour battery can power the microcell for around 34 hours alone when active. For serving more users or in a more intensive environment with more power consumption, it may be necessary to increase the capacity of the battery pack and solar generation of the solar panels or intermittently run a generator.

## Satellite Connection

External access to the internet, calling, and SMS to external mobile devices will be connected through existing networks of satellites. Several methods exist to connect to satellite “constellations,” which are large satellite networks that transmit data around the globe. Interfacing with these constellations can be done through proprietary hardware that is available from the satellite service providers. These constellations, or other satellite connections, can provide one uniform pipeline to access Internet services. Through this Internet connection, the PCI operator can connect to the web APIs like Google Voice and Twilio as described in the software architecture section.

One such satellite provider is Inmarsat which provides consumer and business services called IsatHub and BGAN to connect to a global network that covers the entire globe except for extreme polar locations

| 14 . BGAN, which stands for Broadband Global Area Network, does not
require complex technical knowledge to set up, as the receiver and transmitter are provided in a pre-configured unit that must not be precisely aimed towards the satellite, just in the general direction. The recommended satellite modem and antenna system will be the Explorer 510 (recommended for BGAN satellite connection):

The Explorer 510

| 15 can provide a data connection up to 464 kBps, which is limited for multi-user
operation and may present a limitation of using a BGAN setup. However, the Explorer 510 is resistant to temperature and humidity while being drop-resistant. Its IP66 rating means it is entirely water and dust sealed

16
. BGAN modems provide simple methods for achieving this initial calibration, for example, using auditory cues to aim the unit in the correct direction (which does not present any issues with language barriers) or even utilizing a smartphone app

17
. A BGAN
modem such as the Explorer 512 outputs through an ethernet cable that can be connected directly to the Linux server without much setup required.

Downsides of the BGAN setup are the low bandwidth and high cost of Internet usage plans: a simple package for example that provides 30 GB at full speed then throttled data at 128 kBps costs $3595.00 per months for three months of service

18
. Other provider packages can charge up to $4,500 for the same connection of 30 GB unthrottled

19
. The most significant advantages of the system, however, are its flexibility and usefulness in diverse weather conditions. BGAN communicates through a lower frequency, the L-band which is less susceptible to rain fade than other satellite dish systems

20
. Specific models are available for BGAN communications that have the modem and transceiver sealed to prevent dust and water damage as well as protected against both hot and cold weather conditions. The costs for terminals vary from $795 to over $5000. Several terminals may be compared here. (http://www.groundcontrol.com/BGAN_Terminal_Comparison_Chart.htm)

An alternative to the BGAN system is the iDirect global satellite constellations use of VSAT transceivers (VSAT stands for “Very-small aperture terminal”). VSAT technologies utilize the more commonly recognizable satellite dishes and are more prone to interruption of service due to weather conditions in the sky, yet the system may be isolated to prevent damage due to water, temperature, dust, or other conditions. The main advantage is that the bandwidth of VSAT technologies is much higher, allowing internet access up to 20 Mbps download and 5 Mbps upload. However, many plans are still capped for usage at similarly high prices as the BGAN solutions. The base price of terminals is also similar, but slightly higher than BGAN terminals as the prices of base models start at $1,364

21
. However, mobile solutions that are designed for rough conditions and transport can be many times more expensive than even high-end BGAN terminals. The large dish and accompanying equipment also are harder to transport to a disaster location regardless of the price because of the weight and bulk. Installation difficulty also scales with the terminal’s size. For these reasons, the BGAN system is the recommended satellite receiver, transmitter, and modem.

## Mounting

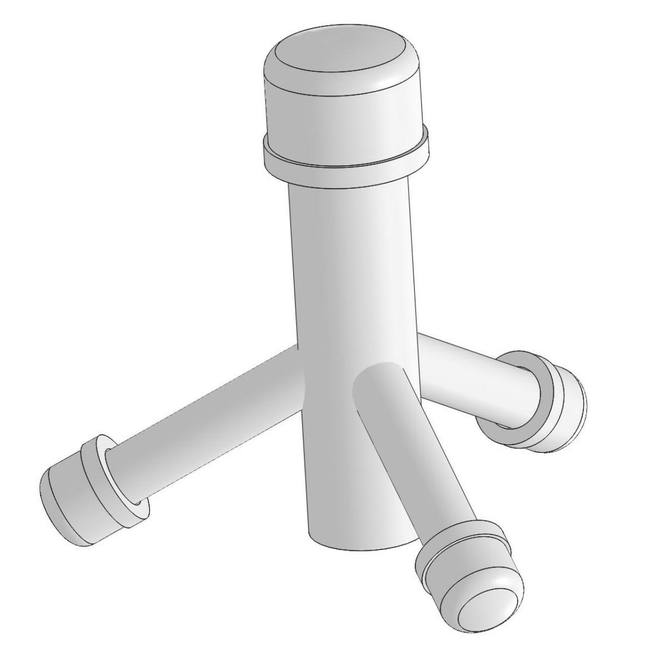
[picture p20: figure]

The antenna, with four monopoles connected, rests inside of an antenna structure that is made out of PVC tubing. The wiring of the monopoles is surrounded by insulation, which fills the space between the tubing and wiring. Each PVC monopole segment is capped, and those caps sealed to the tubing to prevent water or moisture damage.

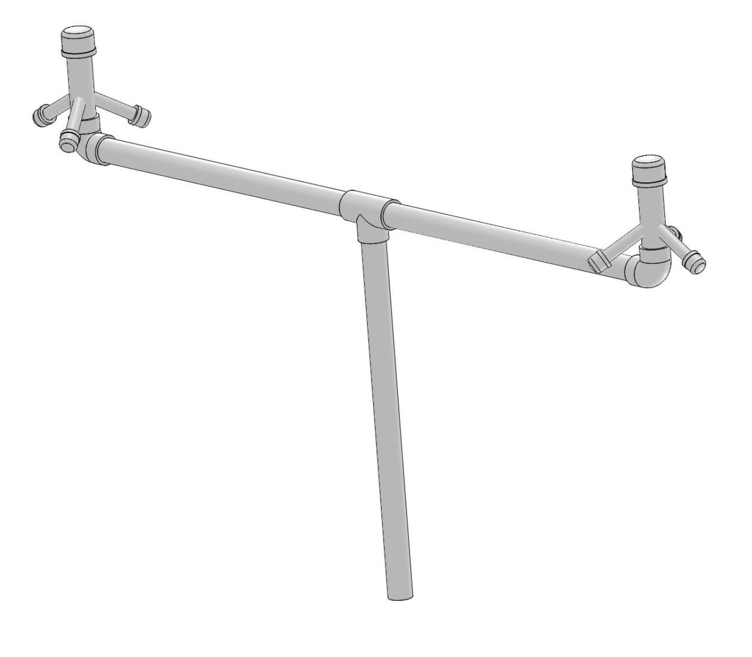
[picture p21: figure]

The entire antenna mast consists of two antenna structures which are helds several wavelengths apart to avoid interference. The antenna mast is approximately 1 meter long and 0.5 meters tall. The coaxial feed lines run in from the bottom of the mast to the individual antennae. The mast is also made out of PVC, which may be taken apart for transport (especially larger segments).

To mount the antenna mast on an existing structure, one should use a base, such as several sandbags or a plate connected to the mast to provide structural stability. Alternatively, one could lengthen the PVC at the bottom to create a larger tower. Still, it is recommended that the tower is segmented, connected by PVC joints, and strengthened with metal inserts. If using a tower, guy wires are highly recommended to provide static stability to the free-standing structure, especially during inclement weather conditions.

When constructing a large tower or handling electronics outdoors, follow location electrical codes and regulations. Safety recommendations about lightning protection, electrical safety, radiation safety, and other guidelines are available here (https://github.com/Ironarcher/portable-cell-initiative/raw/master/documentation/Safety%20Recommendations.docx) (we disclaim any liability).

Weight | Estimate
Component | Weight (kg)
Base Station (bladeRF, Odroid XU-4, cabling, and housing) | 3.5
Antenna Mast | 1.5
Satellite Transceiver | 1.4
Portable Lithium Ion Battery Pack | 18.1
Solar Panel | 11.7
Total weight without power generation or batteries | 6.4
Total microcell weight | 36.2

## Additional Diagrams

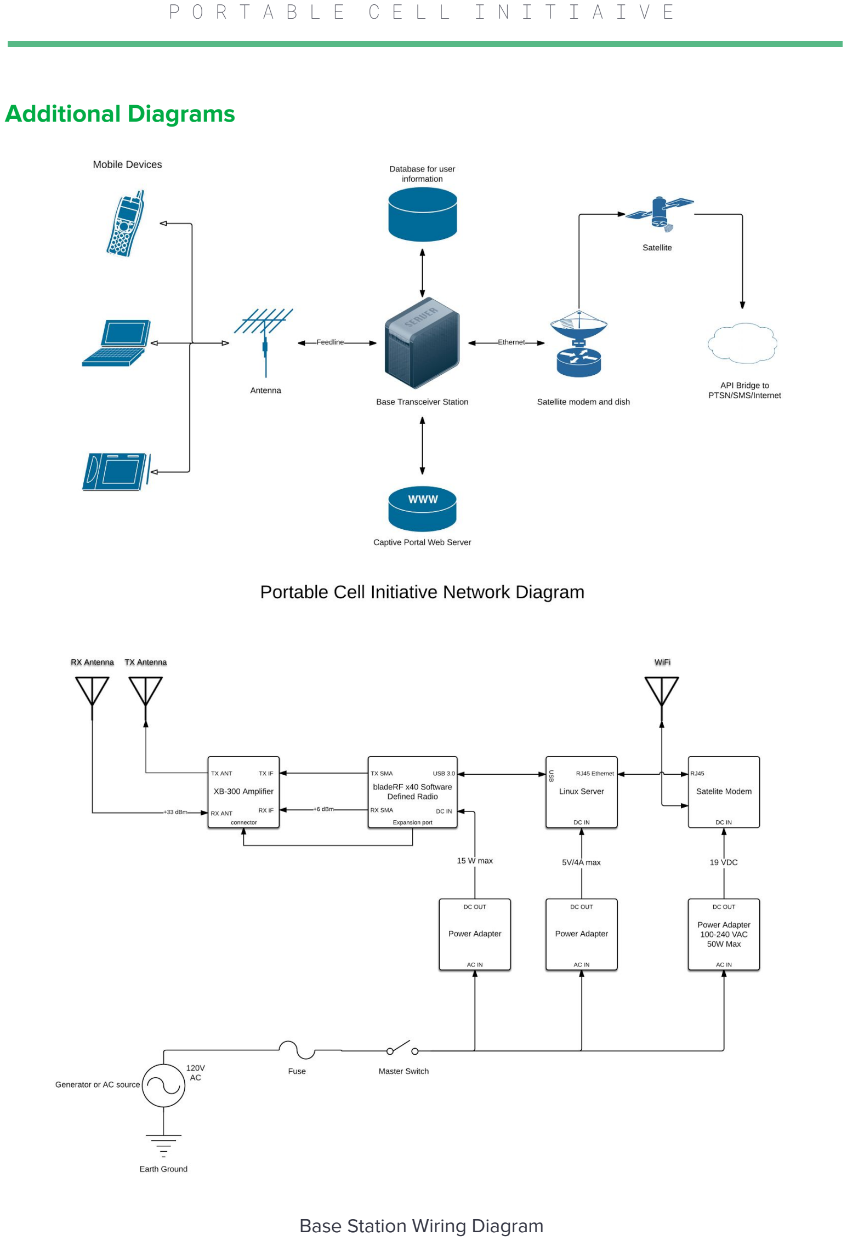
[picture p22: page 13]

Base Station Wiring Diagram

## SOFTWARE ARCHITECTURE

The software that will be leveraged is all open-source and custom scripts and commands that will be required to operate these systems are available on GitHub for free use under the appropriate license.

The software that will be running on the linux server includes OpenBTS, an open-source project for operating cellular network infrastructure such as cell towers on software-defined radios. The operating system used will be Debian, but Ubuntu and centOS are also supported and tested for compatibility. This proposal contains outlines and requirements of the software architecture and thus will serve as an overview. More details on installation and operation are available in other documents.

OpenBTS will be used to operate the “base station” and will run on the linux server to send commands and monitor the software-defined radio. OpenBTS will govern GSM (or “2G”) communications, including voice, SMS, and data services. Included in this software is further access to GPRS, an improved standard.

Note: GPRS stands for “General Packet Radio Service” and allows packets to be routed under the IP protocol. It is often referred to as 2.5G (in between second and third generations).

GPRS is limited in network speed to about 40 kbps, or as fast as a dial-up modem

22
OpenBTS-UMTS is an open-source project that allows access to faster, 3G data speeds but is still developmental and does not support voice or SMS. Therefore, the software architecture will run on a GPRS/GSM system to increase the number of concurrent users on the network and support voice and SMS, but future updates to UMTS are simple.

Other software packages utilized to provide services include Asterisk, to route calls between mobile devices, SIPAuthServe, to register and allow calls to specific handsets, and SMQueue to handle SMS storage and later delivery if the handset is unavailable. OpenBTS converts GSM traffic to use the SIP (Session Initiation Protocol) and RTP (Real-time Transport Protocol) and thus allows voice and SMS connections within the network. Another technology called “OpenRegistration” allows users to create their own subscriber identities as custom SIM cards or registered phone numbers are not required on these temporary networks. Handsets can talk to the cell tower over SMS to create accounts and self-assign phone numbers.

Access to the outside world is available solely through the satellite modem connection that provides a gateway to the Internet for the linux server. Requests through GPRS through the TCP/IP protocol may be fulfilled easily, yet calls and messages through SMS that are directed out of the network are more difficult, as they must be bridged to the PSTN from the SIP and RTP protocols within the cell network.

Note: Connecting to the outside world requires an ITSP or Internet Telephony Service Provider, which routes SIP/RTP signals to the PSTN, or Public Switched Telephone Network which “is the network that carries your voice calls when you call from a landline or cell phone” and “refers to the worldwide network of voice-carrying telephone infrastructure”

23

Services that can GSM devices to the PSTN include Google Voice and Twilio. For example, an exploration on connecting voice services from Asterisk to Google Voice may be found here

24 (https://sgmustadio.files.wordpress.com/2011/05/report_bryantferguson.pdf)

## Captive Portal

A central feature of the Portable Cell Initiative is to, provide not only means of communication between members of the community and emergency workers but also facilitate the response to the disaster at hand. A captive portal is a default web page that appears upon connecting to a network with a web browser and is a common feature of large WiFi networks at airports or hotels. Network traffic may be redirected to a special webpage, which provides users:

- Official updates or warnings from the government or other emergency services
- Maps of the surrounding area with updates, for example through a service like Google Crisis Maps
- Useful web resources and telephone numbers to call
- A forum for community peer-to-peer assistance, for example connecting people who request asylum to other locals who offer places to stay

Note: Connecting through a captive portal is often a means of limiting access to the internet through a network. No such limitation exists, and users can exit the portal and browse the web freely (thus visit any webpage or use any web service). Users can access the web portal like a website at any time.

## COST ESTIMATE

On a per microcell basis using recommended components:

Component | Cost
Odroid XU-4 | $59
BladeRF x40 | $420
XB-300 Radio Amplifier | $149
Explorer 510 | $2176
Housing, cabling, wiring, antenna, structures | $50
Battery Pack (Goal Zero Yeti 1000 Lithium Portable Power Station) (http://www.goalzero.com/p/476/goal-zero-yeti-1000-lithium-portable-power-station) | $1299.95
Solar Panel (Boulder 100 Solar Panel Briefcase) (http://www.goalzero.com/ecommerce/product.i?pid=428) | $299.95
Satellite Internet service package * | $4695/month
Total (cell tower without power infrastructure) | $2854
Total | $4459.90 + $4695/month

*Assuming unlimited data usage worldwide. Actual rates depends on data used and geographic location

The satellite Internet package pricing for BGAN depends on the location of the usage and the extent of data usage by the terminal. Typical plans for unlimited data usage (with 30 GB unthrottled) cost $4,695/month for a 3 month period while the BGAN Link Geo plan which is geographically limited to certain areas (https://satellitephonestore.com/bgan-service) is cheaper at $1,750 per month for 3 months. Typical plans that are not unlimited price the data connection at $4-5 per each additional MB but have low upfront costs

25

Compared to other solutions, such as sending balloons into the stratosphere, or operating full-scale cell tower infrastructure which costs millions of dollars, this solution is several orders of magnitude cheaper.

## MILESTONES

## Design Phase

Complete initial research, cost estimates, CAD models, network and hardware diagrams, and system architecture design. Begin software design by writing automated scripts for the base station server.

## Prototype Phase

Purchase and test base station components with a small antenna and low-power setup. Finalize software and protocols to allow full operation of a minimum of two smartphones on the network, including SMS and calling between the mobile devices, access to the captive portal for information, and external internet access.

## Full-Scale Testing

Create a prototype of the large scale radio antenna and acquire permission to test in a designated area with an FCC experimental radio license to calculate the actual range and network capacity of the system. Test additional functionality like access to the tower with SIM cards from other cellular network providers. Place the base station equipment in prototype casings and test the power supply supplying the system disconnected from the electrical grid. Complete weather testing of all components, including temperature extremes, rain, and snow.

## Deployment

Complete equipment required for deployment of the system into real-world scenarios, including packaging of the full-scale equipment and writing manuals in several languages for ready-use in several countries. Finally, confirm that the system allows connection between multiple cellular towers to create a mesh network, even when the towers are spaced far apart.

## COMPETITORS

## AT&T ARMZ

A similar solution exists by AT&T for government and enterprise operators to create a “picocells,” or small cell sites that connect via satellite to allow communications in the wake of disasters. However, the proprietary nature of the system either requires the use of AT&T’s own satellite systems and networks to operate or requires custom solutions to be designed with experts to set up the cells. The system can only service 7 concurrent calls simultaneously per picocell

26 and is
also limited to using 2G and 2.5G services. The mobile service configuration is also limited to a ½ mile radius, and the system is heavy (weighing an estimated 290 pounds at minimum). This particular system has a limited operational temperature of 5°C to 40°C

2 and the VSAT technology
that is used to connect the picocell to satellites is bulky and harder to point and set up than alternatives like BGAN

27
. Data speeds of BGAN solutions may be limited in comparison, but each type of connection is well above the minimum requirements for cell tower operation

28
. VSAT
solutions are also more prone to weather such as rain and extreme conditions like snow and strong winds

29
. Most importantly, the current ARMZ solution is only viable in the continental U.S. while this proposal suggests a system that would work in any environment, anywhere in the globe without any need for modification. The open sourced nature, the cheap costs of components, the flexibility of operation, and the resistivity to adverse weather conditions of the Portable Cell Initiative make it more advantageous to use than alternative ground-based solutions.

## Google Loon

Google has created a solution which uses “ balloons to help provide internet service to people in hard-to-reach places”

30 and has an experimental license from the F.C.C to roll out Internet service in Puerto Rico after Hurricane Maria, according to the L.A. Times. Issues for achieving connectivity in disaster areas include requiring integration with the existing telecommunication companies in Puerto Rico, as the balloons themselves cannot deliver the signals alone. The balloons suffer disadvantages, such as requiring dedicated ground links to achieve Internet connectivity and constant maintenance and care to operate. The complexity of incorporating a flying device into the system makes the solution less practical for fast deployment and reliable operation. Altogether, it is simpler to have a ground-based microcell like proposed by the Portable Cell Initiative which can exist without outside requirements for power and connection and also provide telephone communications and SMS without needing integration with existing cellular carriers. Although integration is possible to “expand” the existing telecommunication framework with microcells, service is also available as a standalone carrier without having to re-issue SIM cards to subscribers.

## TEAM

Arpad | Kovesdy | is a freshman studying aerospace engineering at the University of Southern
California in Los Angeles. Arpad is a recipient of the prestigious Presidential scholarship and member of the W.V.T Rusch Undergraduate Engineering Honors Program at the Viterbi School of Engineering. He founded the project in 2017 to address the growing need for portable systems of cellular communications around the world, and especially for disaster areas such as hurricane-devastated locations in the United States. He currently leads the software and hardware design of the project and has extensive experience with engineering front-end and back-end systems for websites and apps. He has four years of experience in robotics competitions like the First Tech Challenge and has completed research at the University of Tennessee Knoxville in Materials Science. Arpad also spends time working at the Rocket Propulsion Laboratory at U.S.C., where undergraduate students design, build and launch rockets. Arpad is the team leader of the Portable Cell Initiative.
Joseph | Stafford | is a freshman studying computer science at Michigan State University. He is part
of the Honors College at MSU and is currently researching solutions to reducing parking congestion through building an app that reports the number of parking spots available on campus. Joseph was also involved with robotics during high school and focused on the development of autonomous guidance and control in competitions for FIRST. Finally, Joseph is a skilled chess player, competing in regional tournaments around the Mid-South.

## Endnotes

1. http://www.arrl.org/single-band-dipoles
2. https://commons.wikimedia.org/wiki/File:Antenne_gp_vhf_3.jpg (CC BY-SA 3.0) (https://creativecommons.org/licenses/by-sa/3.0/)
3. http://www.wirelessinnovation.org/assets/documents/SoftwareDefinedRadio.pdf
4. https://www.nuand.com/blog/product/bladerf-x40/
5. https://www.nuand.com/blog/product/amplifier/
6. https://www.nuand.com/blog/product/power-supply/
7. https://www.pidramble.com/wiki/benchmarks/power-consumption
8. http://www.hardkernel.com/main/products/prdt_info.php?g_code=G143452239825&tab_idx=1
9. https://magazine.odroid.com/wp-content/uploads/odroid-xu4-user-manual.pdf#page=16
10. https://www.pidramble.com/wiki/benchmarks/power-consumption and https://www.raspberrypi.org/documentation/hardware/raspberrypi/power/README.md
11. http://www.mikronauts.com/hardkernel/hardkernel-odroid-xu4-review/11/
12. https://github.com/Nuand/bladeRF/wiki/bladeRF-Power-Consumption
13. http://www.groundcontrol.com/bgan/Explorer_510_BGAN_Brochure.pdf
14. https://www.inmarsat.com/service/bgan/
15. http://www.groundcontrol.com/bgan/Explorer_510_BGAN_Brochure.pdf
16. http://www.dsmt.com/resources/ip-rating-chart/
17. http://www.groundcontrol.com/bgan/Explorer_510_Quickstart_Guide.pdf
18. http://www.groundcontrol.com/BGAN_Link.htm
19. http://www.groundcontrol.com/BGAN_Standard_Plus.htm
20. http://www.groundcontrol.com/BGAN-FAQ.htm#26
21. http://www.groundcontrol.com/Satellite_Dish_Equipment.htm
22. https://www.gsma.com/aboutus/gsm-technology/edge
23. https://www.twilio.com/docs/glossary/what-is-pstn
24. https://sgmustadio.files.wordpress.com/2011/05/report_bryantferguson.pdf
25. https://satellitephonestore.com/bgan-service
26. https://www.corp.att.com/stateandlocal/docs/remote_mobility_zone.pdf
27. http://www.networkinv.com/bgan-or-vsat-comparing-the-technologies/
28. http://www.groundcontrol.com/BGAN-FAQ.htm#6
29. http://www.groundcontrol.com/BGAN-FAQ.htm#26
30. http://www.latimes.com/business/la-fi-google-puerto-rico-20171009-story.html

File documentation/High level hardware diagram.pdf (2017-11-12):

## High-Level Architecture Diagram

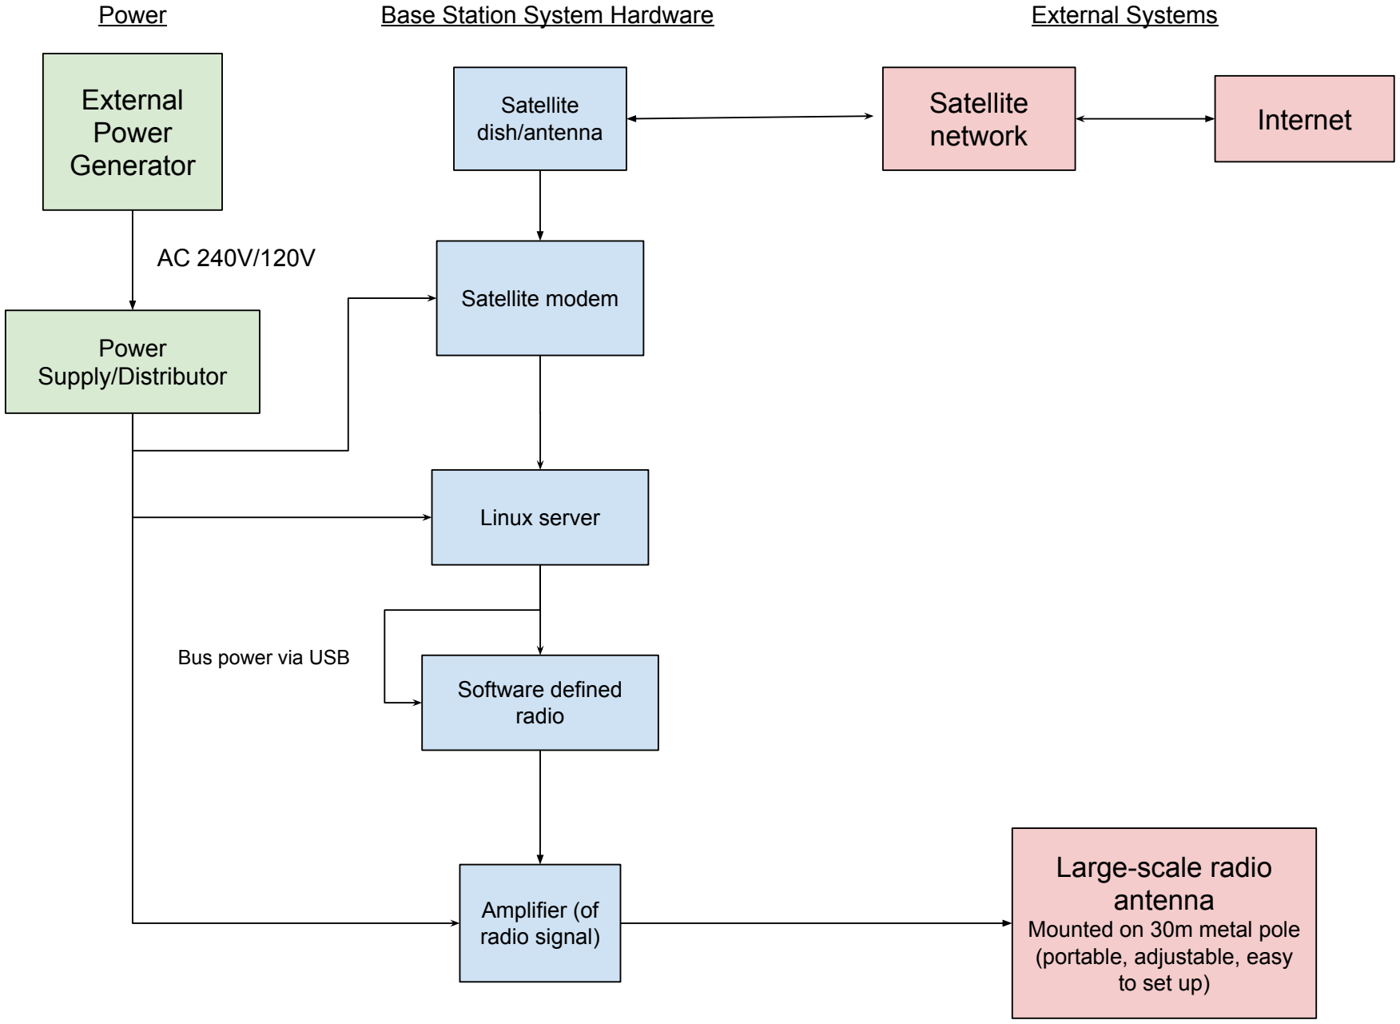
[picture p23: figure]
Satellite dish/antenna; Satellite modem; Linux server; Software defined radio; Amplifier (of radio signal); Large-scale radio antenna; Mounted on 30m metal pole (portable, adjustable, easy to set up); Satellite; network; Internet; Power; Base Station System Hardware; External Systems; External Power Generator; Power Supply/Distributor; Bus power via USB

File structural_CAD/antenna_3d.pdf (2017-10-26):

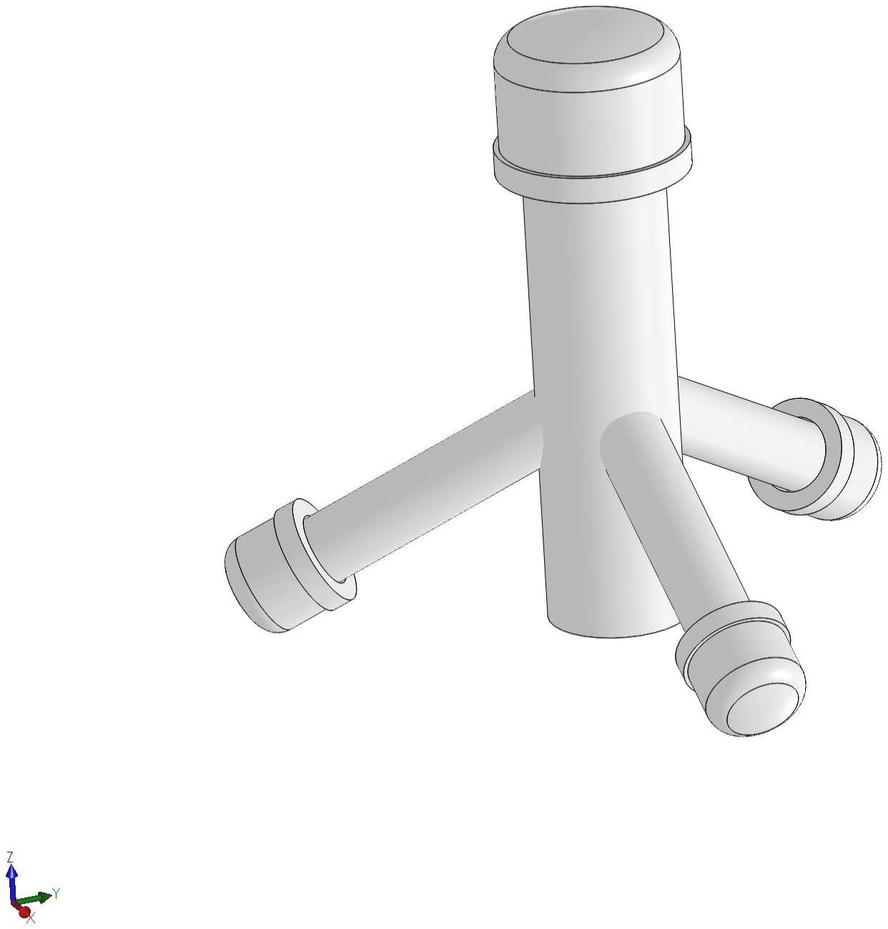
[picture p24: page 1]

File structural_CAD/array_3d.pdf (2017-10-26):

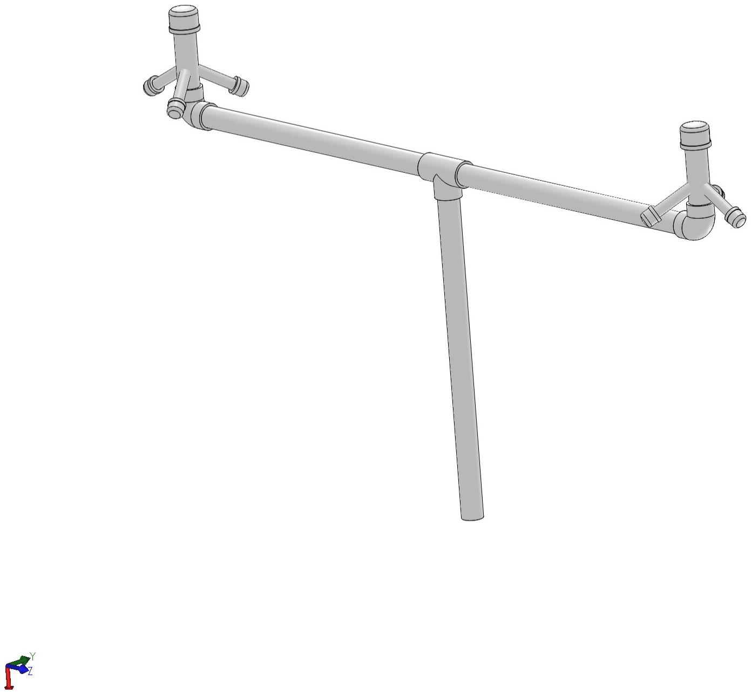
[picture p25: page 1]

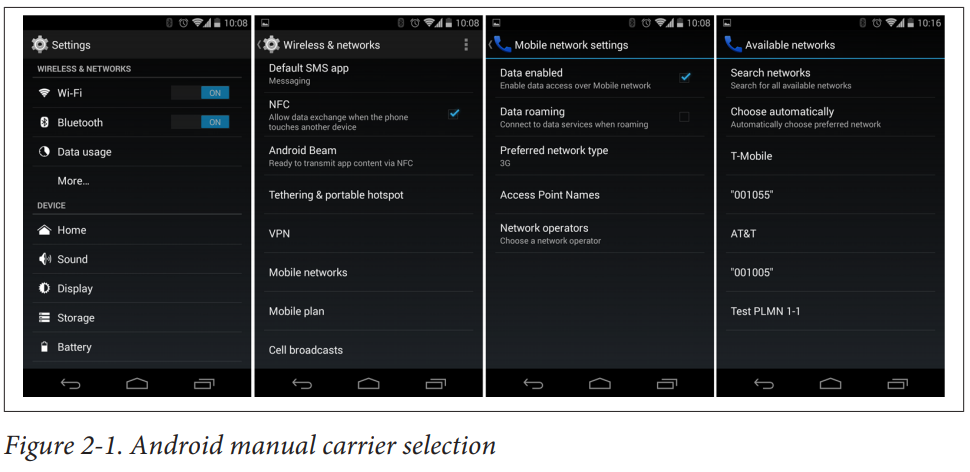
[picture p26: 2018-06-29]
wiki2.png

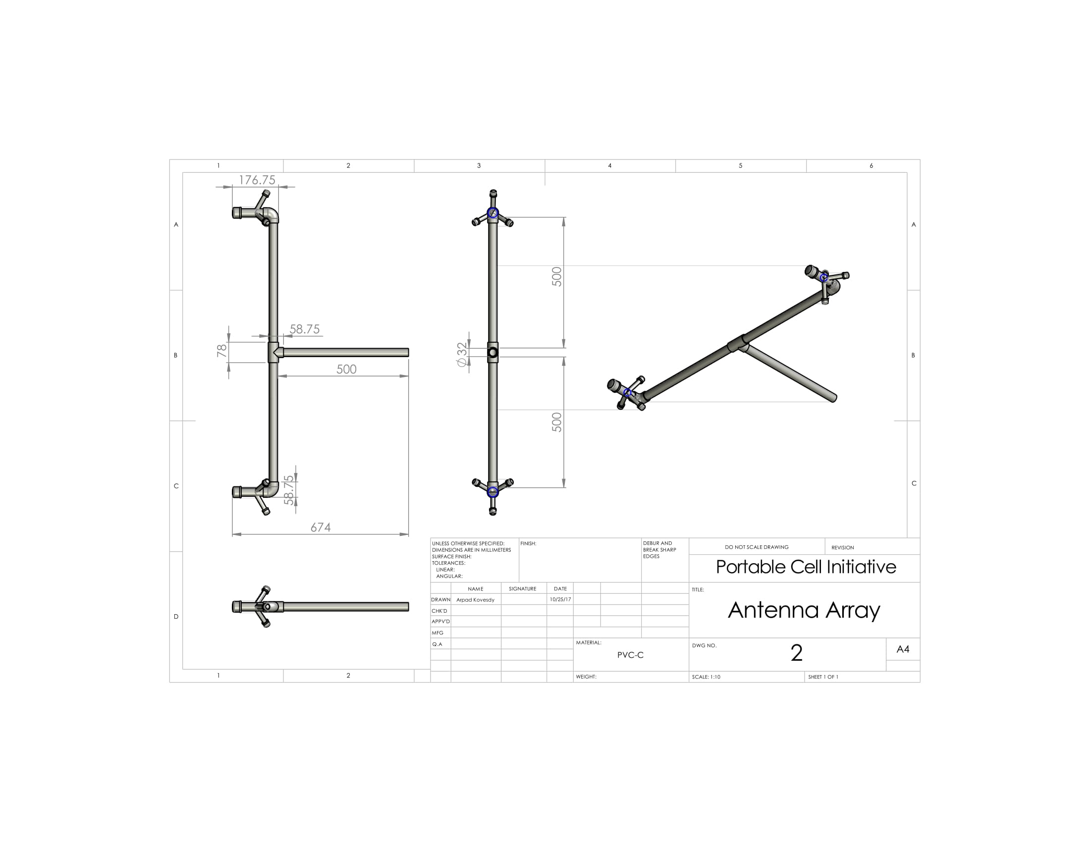
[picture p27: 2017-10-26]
structural_CAD/img/antenna_array-1.jpg

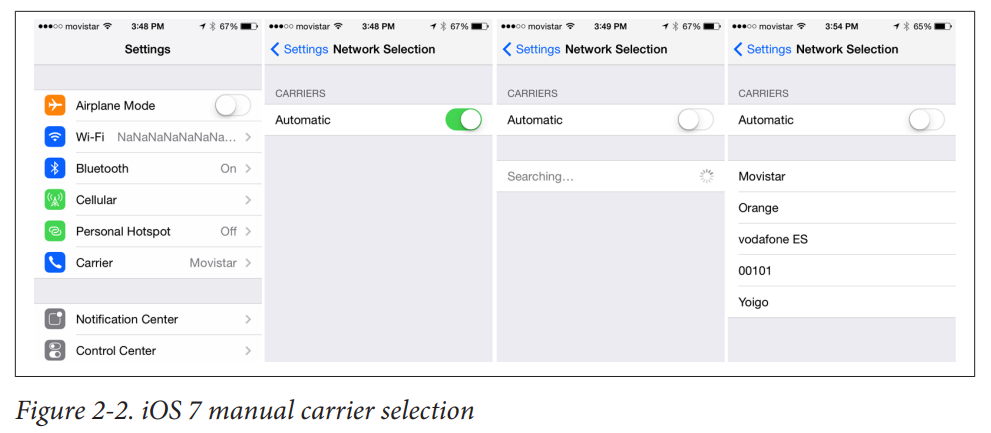
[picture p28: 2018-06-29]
wiki1.png

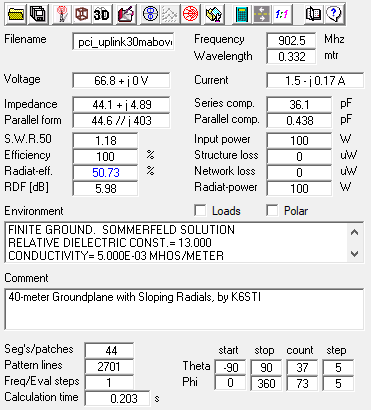
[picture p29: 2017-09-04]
antenna_EM_modeling/pci_uplink30maboveearth02.bmp

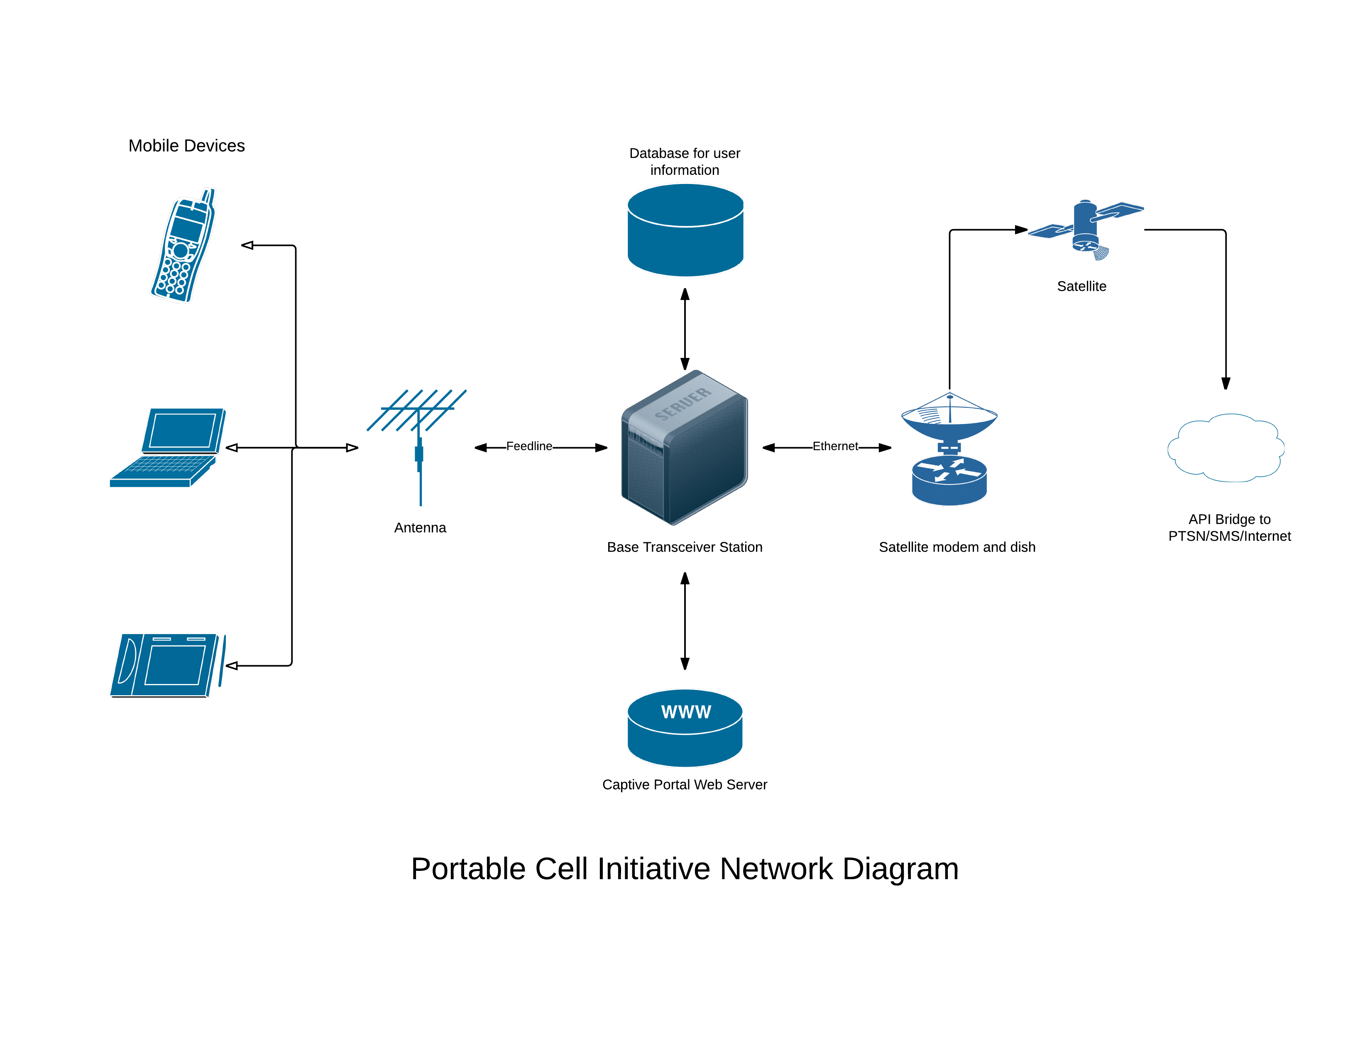
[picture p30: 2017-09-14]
documentation/Portable Cell Initiative Network Diagram.png

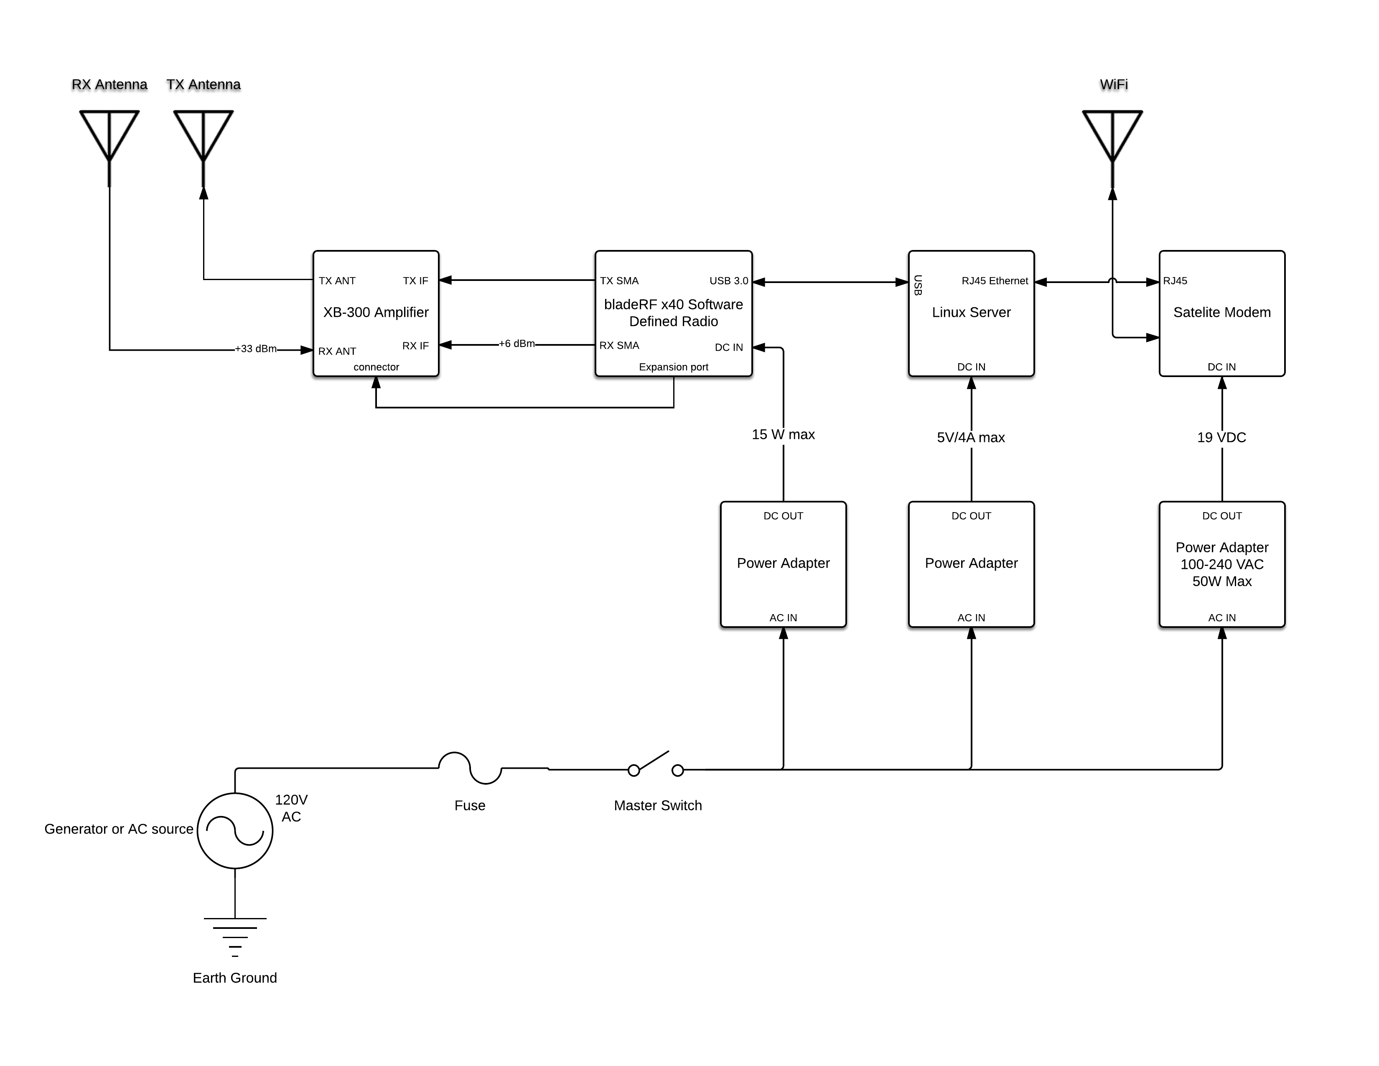
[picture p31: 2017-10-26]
documentation/Circuit Diagram.png

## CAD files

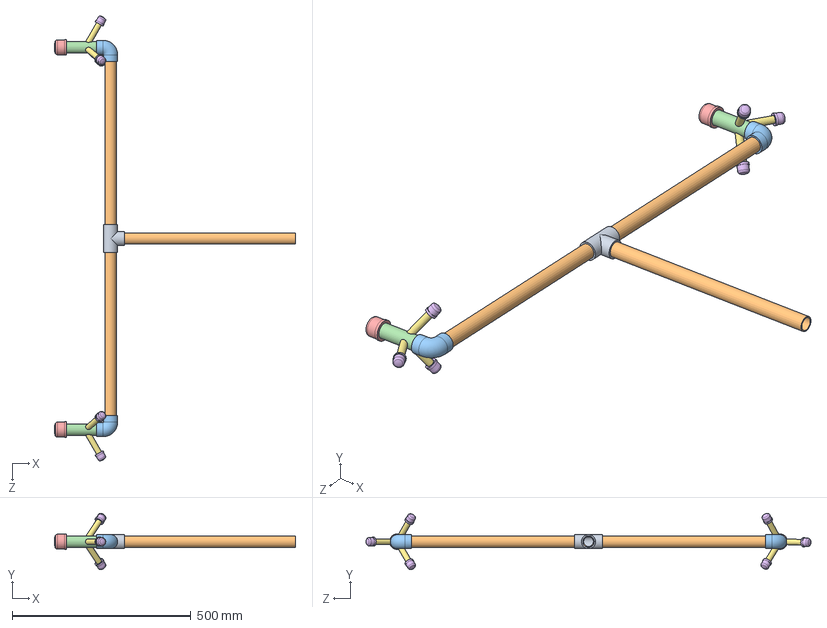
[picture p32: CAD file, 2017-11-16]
structural_CAD/midsection.SLDASM
674.1 x 157.1 x 1243.4 mm
pvc_32_2mm_90tee
pvc_32_2mm_straight500mm x 3
pvc_32_2mm_elbow x 2
pvc_32mm_straight128mm x 2
pvc_32mm_cap x 2
pvc_17mm_cap x 6
pvc_17mm_straight79mm x 6

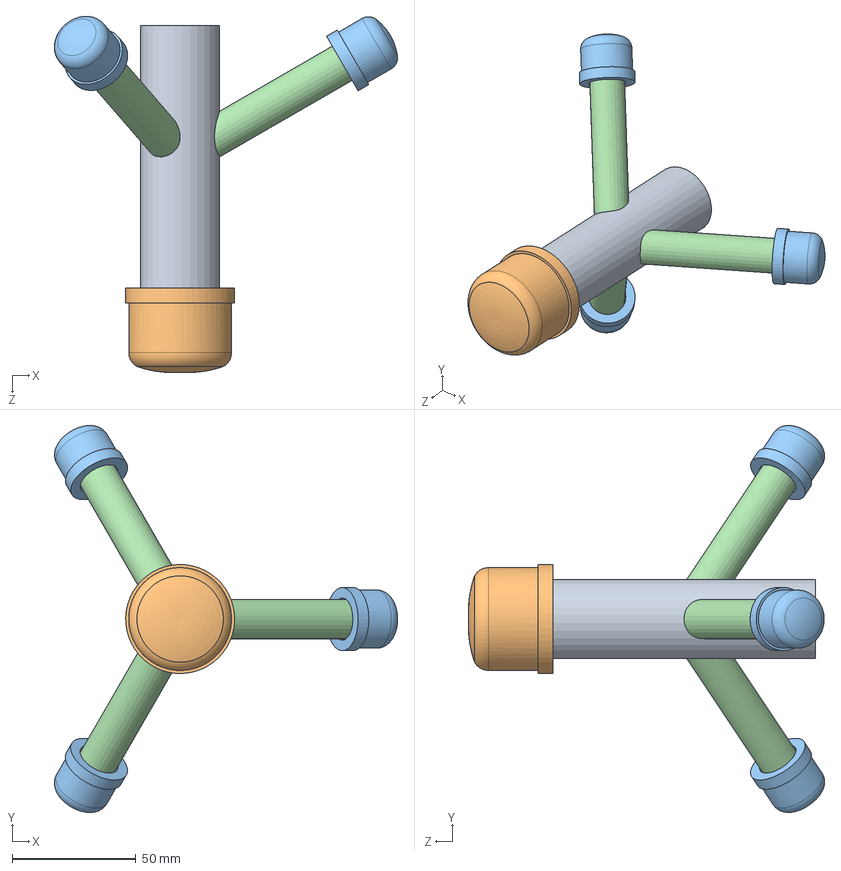
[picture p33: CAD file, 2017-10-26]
structural_CAD/antenna_assem.SLDASM
138.5 x 156.2 x 143.8 mm
pvc_32mm_straight128mm
pvc_32mm_cap
pvc_17mm_cap x 3
pvc_17mm_straight79mm x 3

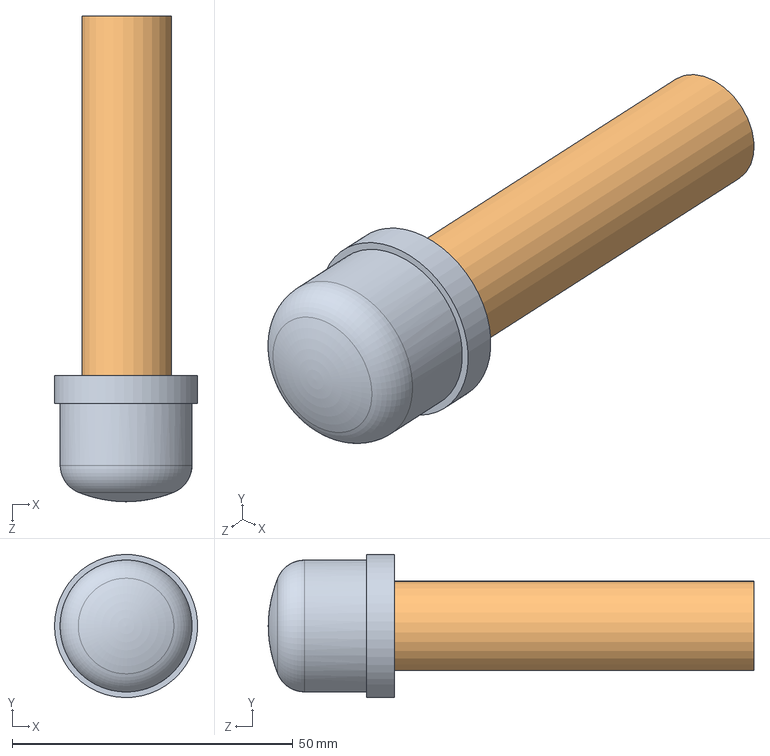
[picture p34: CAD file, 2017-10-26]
structural_CAD/gndplane_segment.SLDASM
25.5 x 25.5 x 86.5 mm
pvc_17mm_cap
pvc_17mm_straight79mm

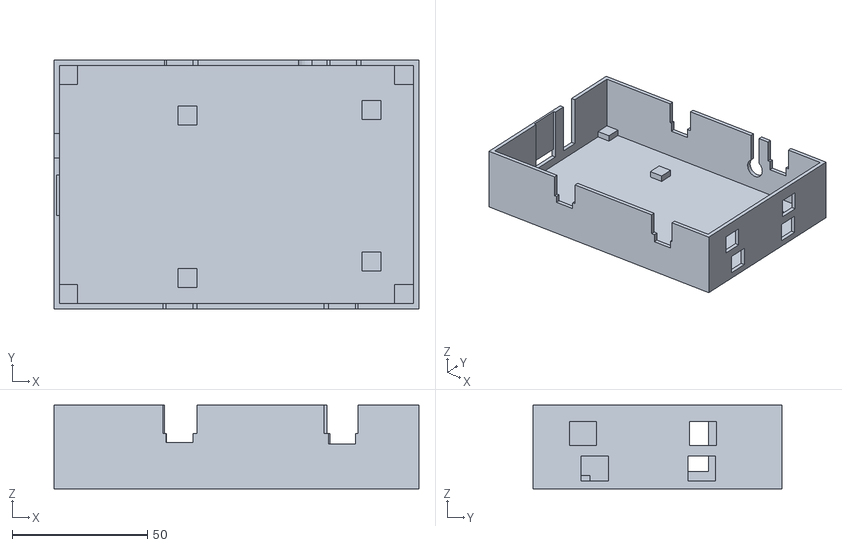
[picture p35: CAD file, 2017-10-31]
structural_CAD/housing/bladerf_case/bladerf+daughterboard_base.stl
134.8 x 92.0 x 31.0

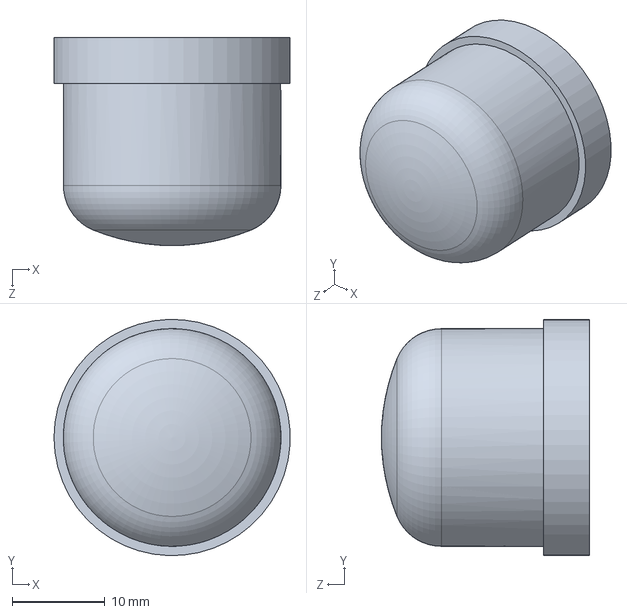
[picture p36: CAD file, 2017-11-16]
structural_CAD/pvc_17mm_cap.SLDPRT
25.5 x 25.5 x 22.5 mm

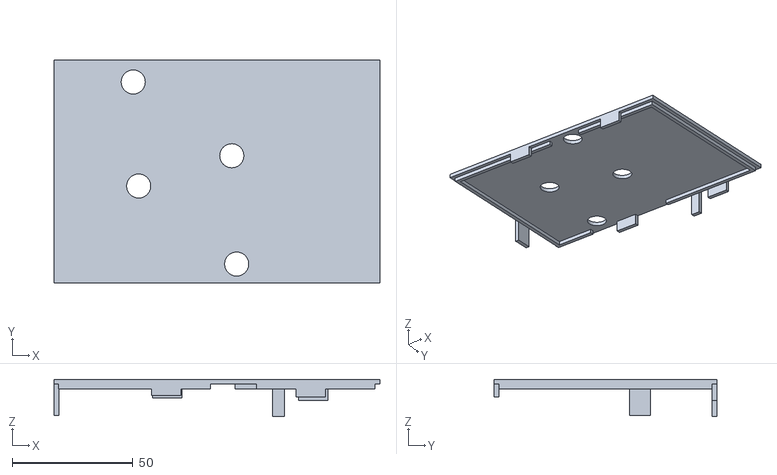
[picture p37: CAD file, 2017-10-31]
structural_CAD/housing/bladerf_case/bladerf+daughterboard_lid.stl
134.8 x 92.0 x 15.5

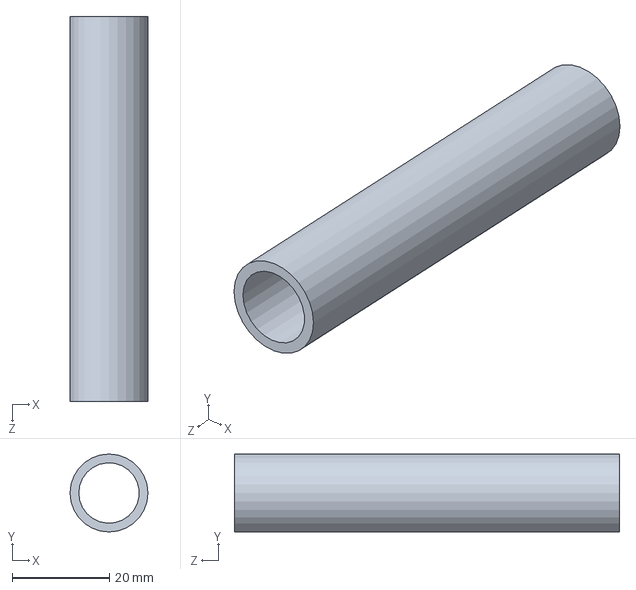
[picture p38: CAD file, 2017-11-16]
structural_CAD/pvc_17mm_straight79mm.SLDPRT
16.0 x 16.0 x 79.0 mm

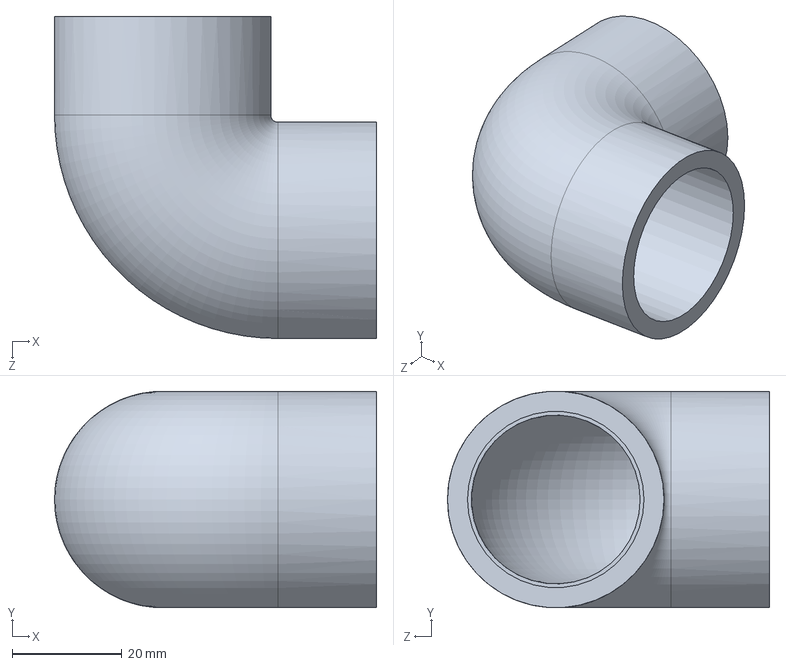
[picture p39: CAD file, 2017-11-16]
structural_CAD/pvc_32_2mm_elbow.SLDPRT
58.8 x 39.5 x 58.8 mm

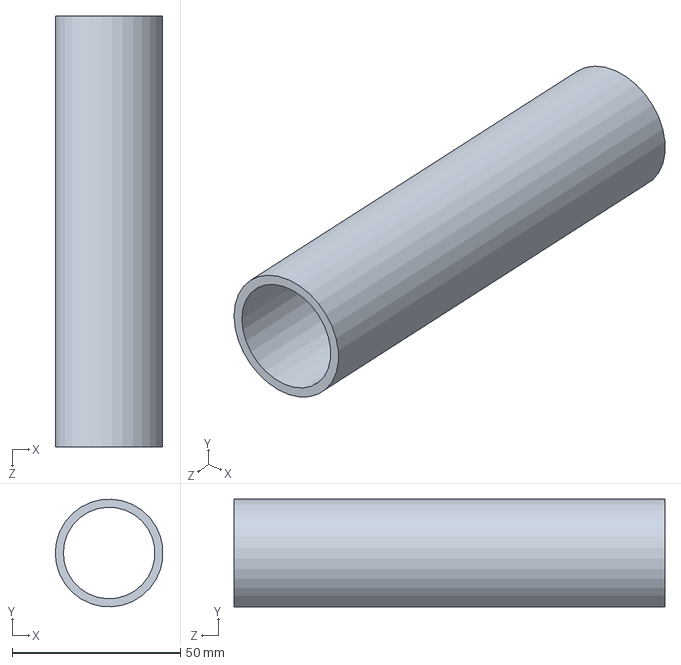
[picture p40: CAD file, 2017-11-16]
structural_CAD/pvc_32mm_straight128mm.SLDPRT
31.9 x 32.0 x 128.0 mm

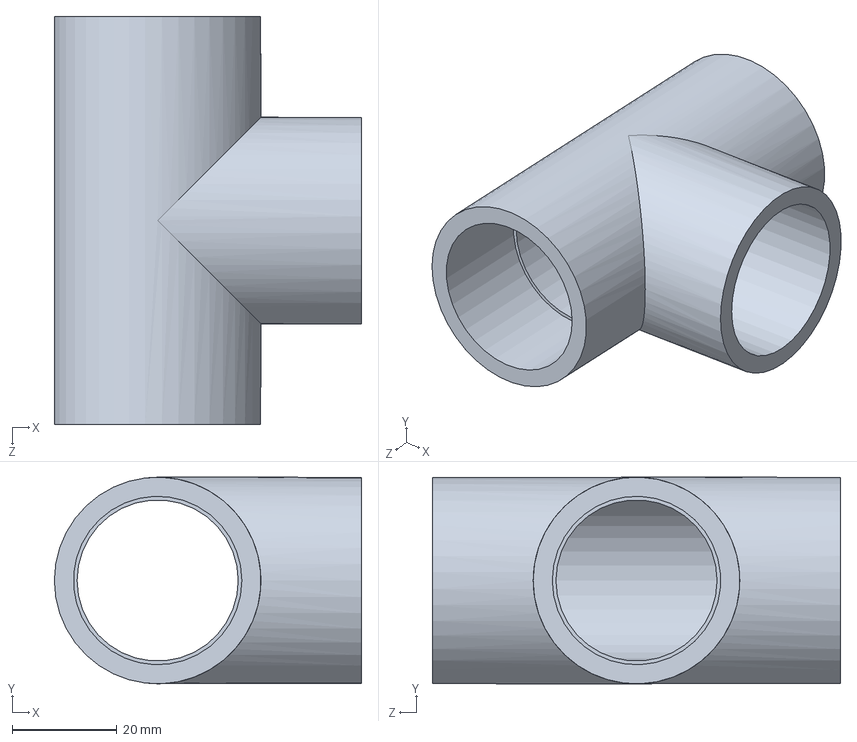
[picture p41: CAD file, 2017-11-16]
structural_CAD/pvc_32_2mm_90tee.SLDPRT
58.8 x 39.5 x 78.0 mm

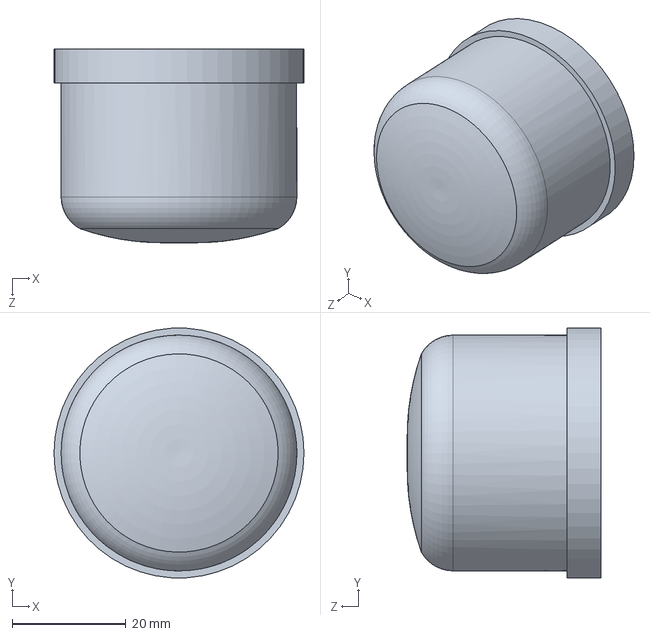
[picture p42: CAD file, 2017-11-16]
structural_CAD/pvc_32mm_cap.SLDPRT
44.0 x 43.9 x 34.1 mm

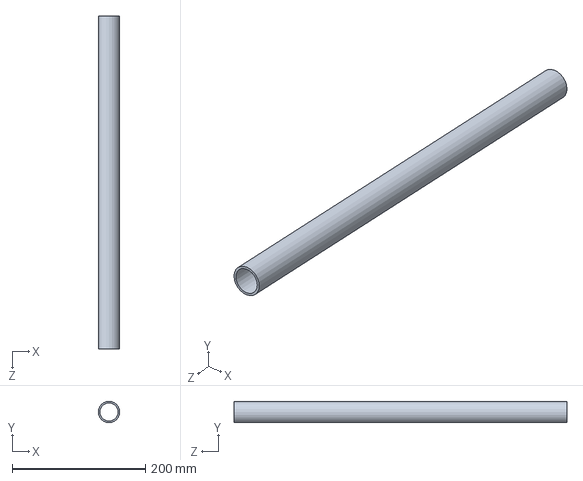
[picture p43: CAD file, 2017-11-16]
structural_CAD/pvc_32_2mm_straight500mm.SLDPRT
32.0 x 32.0 x 500.0 mm

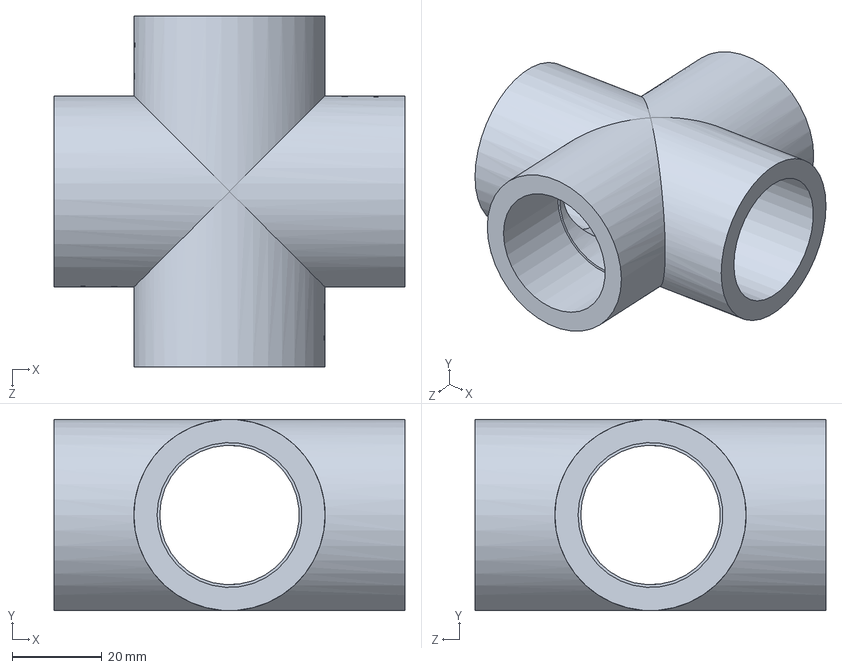
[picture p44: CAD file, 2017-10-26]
structural_CAD/pvc_32_2mm_cross.SLDPRT
78.0 x 42.5 x 78.0 mm

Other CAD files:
structural_CAD/pvc_32_2mm_straightsection.SLDPRT
structural_CAD/antenna_assem.SLDDRW
structural_CAD/midsection.SLDDRW

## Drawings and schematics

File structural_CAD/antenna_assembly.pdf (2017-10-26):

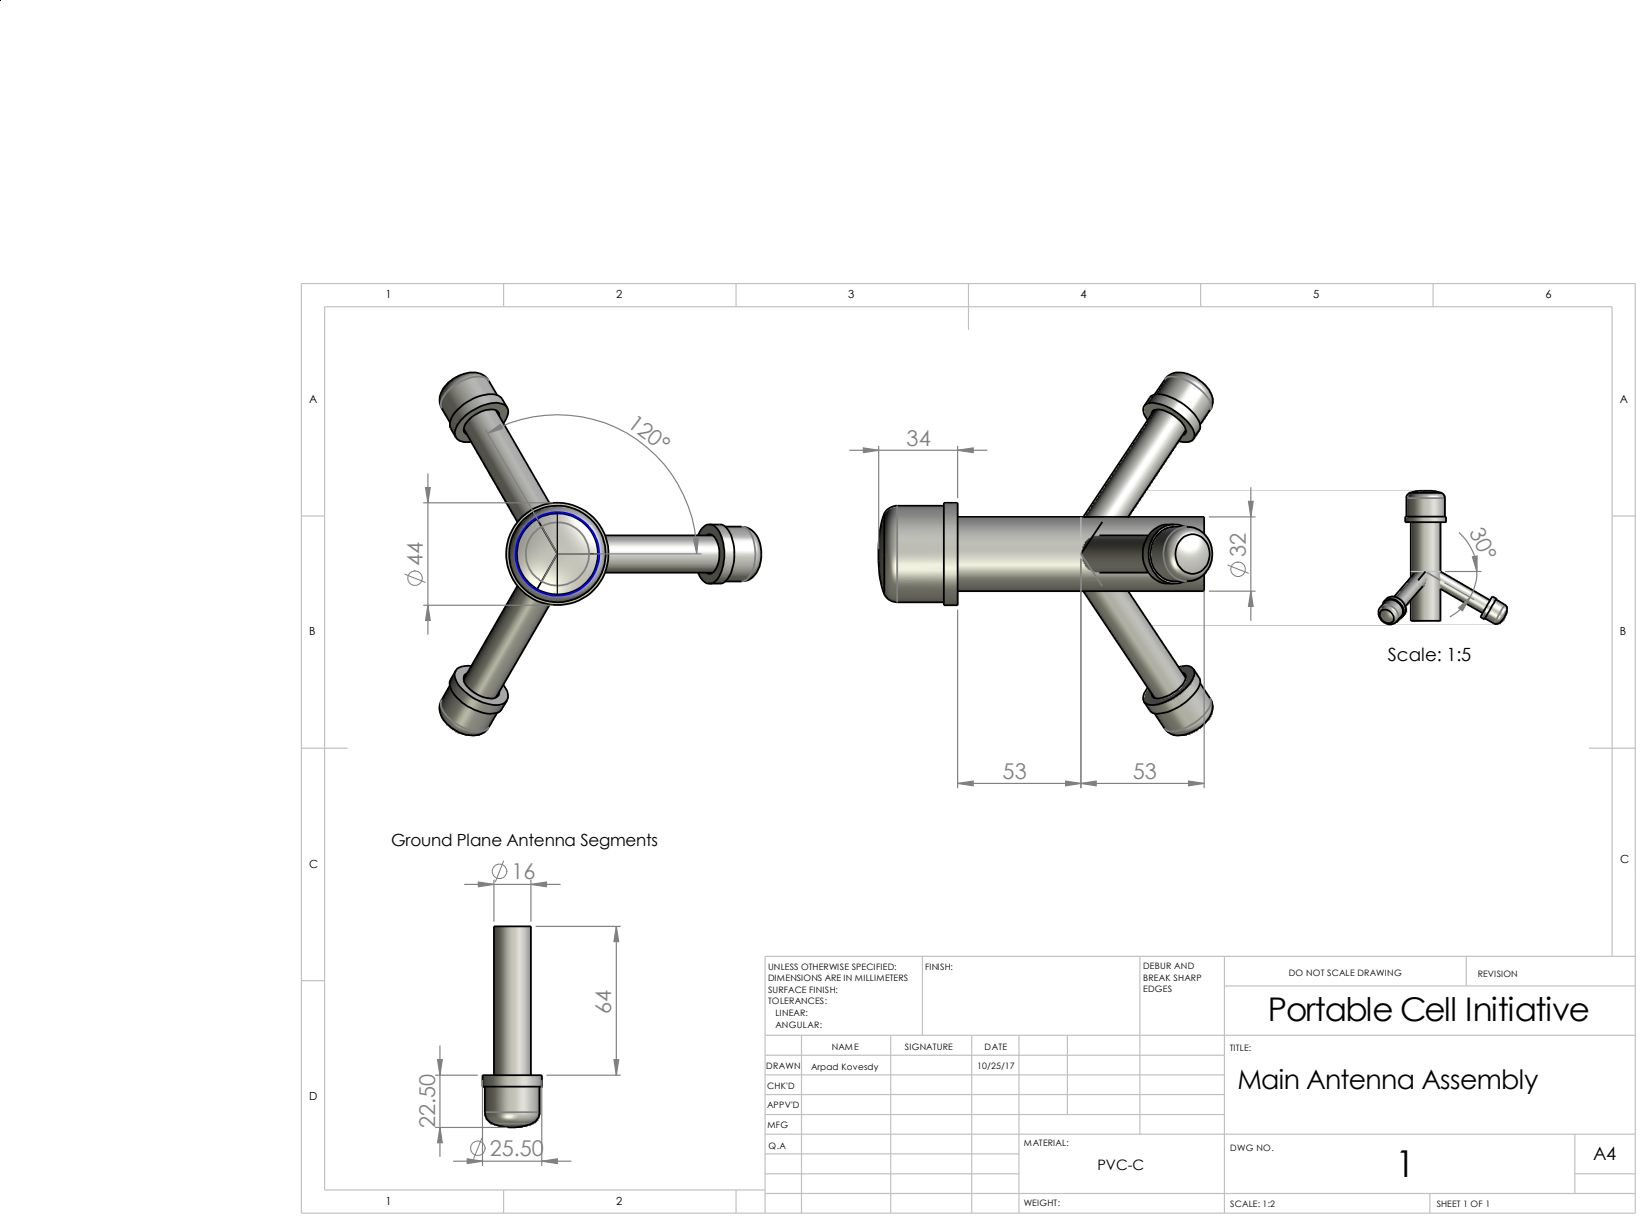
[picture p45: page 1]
FINISH:; DEBUR AND; BREAK SHARP EDGES; DO NOT SCALE DRAWING; REVISION; WEIGHT:; 1 CALE: 1:2; SHEET 1 OF; Scale: 1:5

Ground Plane Antenna Segments

UNLESS OTHERWISE SPECIFIED:
DIMENSIONS ARE IN MILLIMETERS
SURFACE FINISH:
TOLERANCES:
LINEAR:
ANGULAR:

Portable Cell Initiative

NAME | S | DAT E IGNATURE | | | | TITLE: Main Antenna Assembly

DRAWN | Arpad Kovesdy | | 10/25/17
CHK'D
APPV'D
MFG
Q.A | | | | MATERIAL: PVC-C | 1 DWG NO. | A4

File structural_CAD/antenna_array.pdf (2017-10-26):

176.75

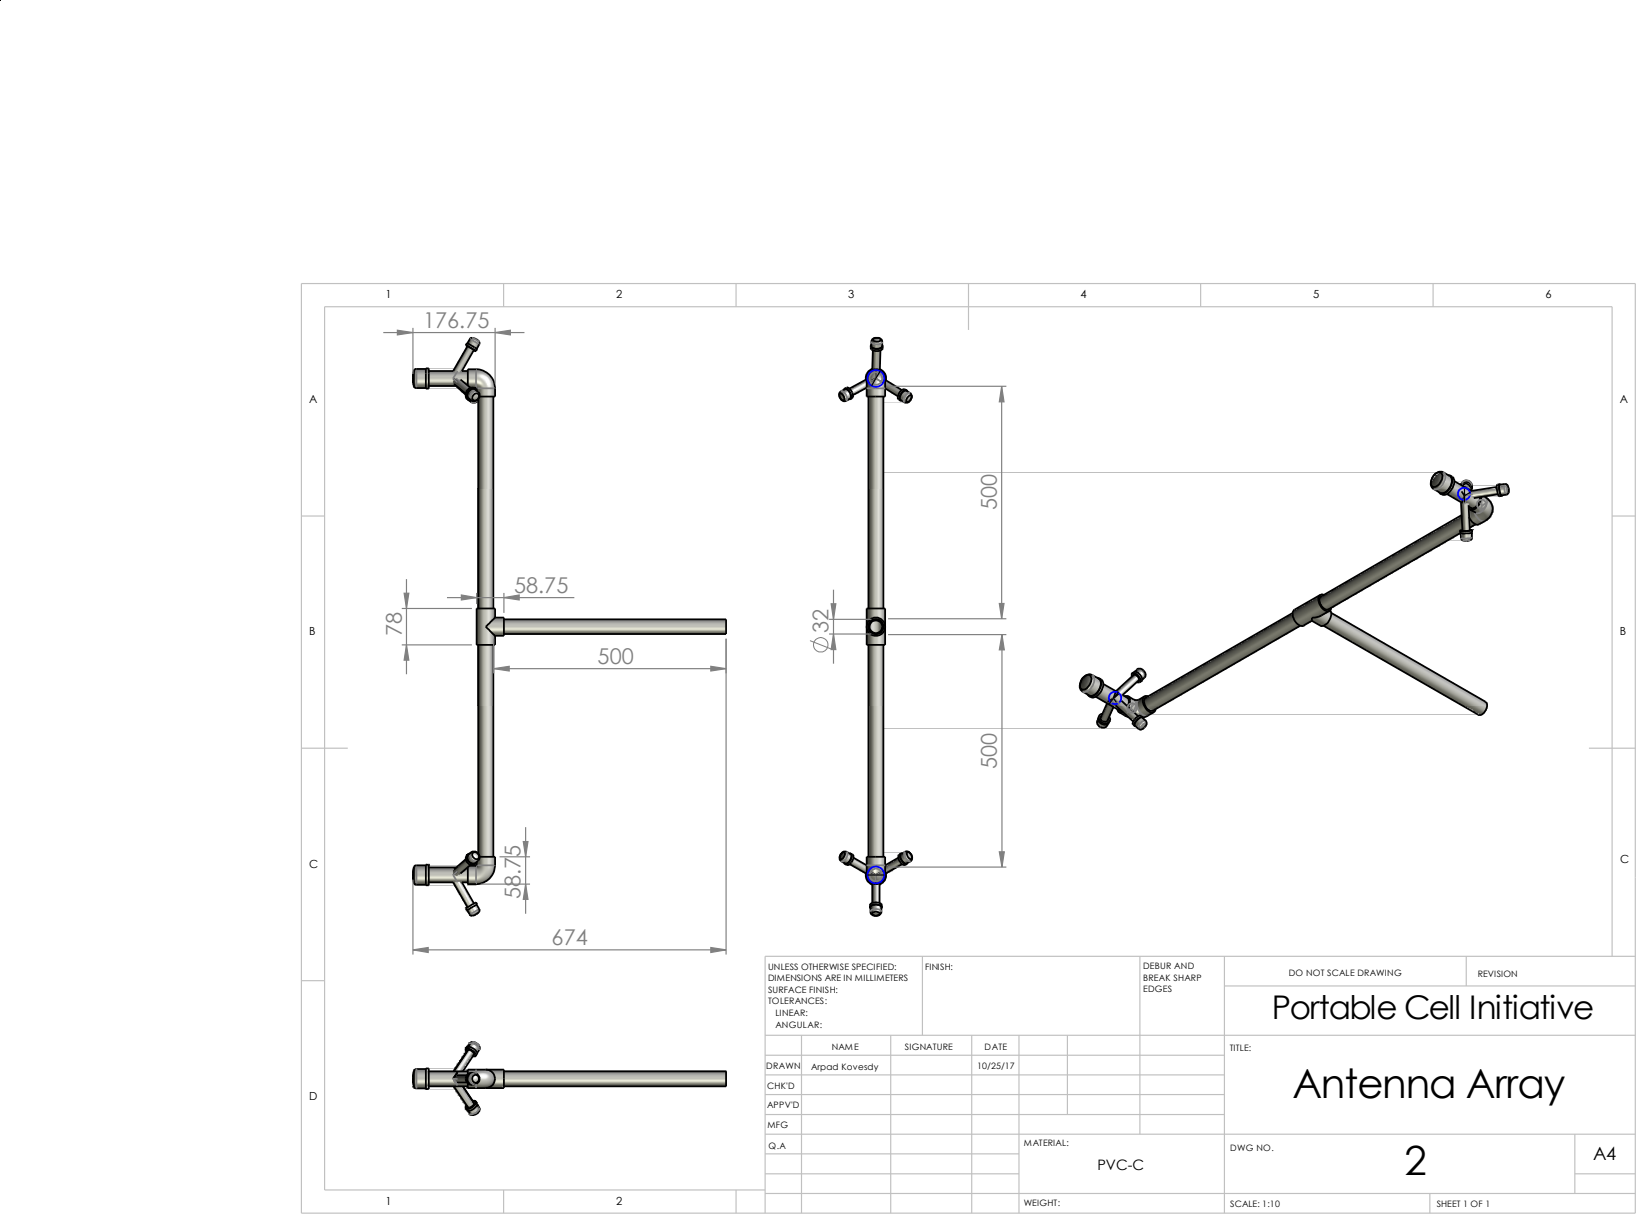
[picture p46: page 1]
FINISH:; DEBUR AND; BREAK SHARP EDGES; DO NOT SCALE DRAWING; REVISION; WEIGHT:; 1 CALE: 1:10; SHEET 1 OF

UNLESS OTHERWISE SPECIFIED:
DIMENSIONS ARE IN MILLIMETERS
SURFACE FINISH:
TOLERANCES:
LINEAR:
ANGULAR:

Portable Cell Initiative

NAME | S | DAT E IGNATURE | | | | TITLE: Antenna Array

DRAWN | Arpad Kovesdy | | 10/25/17
CHK'D
APPV'D
MFG
Q.A | | | | MATERIAL: PVC-C | 2 DWG NO. | A4

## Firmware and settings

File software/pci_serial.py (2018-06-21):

import serial
import time
import telnetlib
import time

serialPORT = "/dev/ttyACM0"
telnetHOST = "localhost"
telnetPORT = 5038

try:
	ser = serial.Serial(serialPORT, 9600, timeout=1)
except Exception, e:
	print(e.message)
	exit(0)

def sendCommand(commandlist):
	commandlist.insert(0, 0xFE) #Inserts the incoming command character into the beginning
	for i in range(0, len(commandlist)):
		ser.write(chr(commandlist[i])) #Write the commands in order

def updateScreen(line1, line2):
	sendCommand([0x58]) #Clear the screen
	ser.write(line1 + "\r") #Writes first line with newline character
	ser.write(line2) #Writes second line

#i is an integer from 0 to 256 which describes the brightness of the screen
def setBrightness(i):
	sendCommand([0x99, i])

def setSplashScreen(line1, line2):
	command = [0x40]
	for char in line1:
		command.append(ord(char)) #Appends the unicode value of the given character for each character in the given strings
	for char in line2:
		command.append(ord(char))
	sendCommand(command) #Sets the splash screen

def getTelnetResponse(command):
	#Get the response data from a telnet command
	host = "localhost"
	port = 5038
	try:
		tn = telnetlib.Telnet(host, port) #Star the telnet connection
		tn.write("command\n") #Etner command to reload yatebts
		try:
			data = tn.read_eager()
			return data
		except Exception, e:
			print(e.message)
			return None
		tn.close() #Close the telnet connection
	except Exception, e:
		print e.message
		return None

def sendTelnetCommand(tn, command):
	tn.write(command + "\r") #Write command to telnet with return character
	time.sleep(0.5) #Delay is necessary for telnet system to catch up
	data = tn.read_very_eager() #Read everything output right after sending write
	return data.split("\r\n") #Split the data by the newline symbols used by the yate telnet service

#setSplashScreen("Portable Cell", "Hermes 1")
#Reminder: set the splash screen in the initialization script
setBrightness(200) #Set initial brightness
updateScreen("Welcome", "Starting") #Set initial screen
print('Screen updated with test image')

state = "yateoff"
while True: #Loop forever (only exit on restart)
	#Initialize the telnet interface
	try:
		tn = telnetlib.Telnet(telnetHOST, telnetPORT) #Start the telnet connection
		time.sleep(0.5)
		tn.read_very_eager() #Clear output from connection
	except Exception, e:
		print e.message
		state = "yateoff"
	else:
		#If such an error does not occur (the telnet connection is made),
		state = "yateon" #Report that yate is operating
	
	if state == "yateoff":
		time.sleep(10) #If yate is not operating, sleep then check again
	elif state == "yateon": #When yate is on
		while True: #Loop forever (until the connection is closed, then report it)
			subscriber_number = "!"
			connection_number = "!"
			try:
				#Collect data from telnet
				subscribers_data = sendTelnetCommand(tn, "nipc list registered") #Check number of subscribers registered
				if subscribers_data[0].startswith("IMSI"): #If data is as expected
					subscriber_number = str(len(subscribers_data)-3)
				else:
					subscriber_number = "?"
				
				#Check the number of GPRS connections (lists active connections in most cases), except for checking chans during active calls
				gprs_data = sendTelnetCommand(tn, "mbts gprs stat")
				if gprs_data[0].startswith("GSM"): #Correct style of output
					connection_number = gprs_data[1].split()[4][-1] #Extract from string the number of active GPRS connections
				else:
					connection_number = "?"

				#Maybe check the uptime of the system, 
			except Exception, e: #When the connection closes
				print(e.message) #Purely print error for debugging purposes
				state = "yateoff" #Reset state to original
				time.sleep(5) #Prevent too many connection attempts to telnet by sleeping
				break #Exit out of secondary while loop
			else:
				#Write to the serial USB display
				if state == "yateon":
					status_string = "ON"
				elif state == "yateoff":
					status_string = "OFF"
				else:
					status_string = "N/A"
				line1 = "TOWER " + status_string
				line2 = "Reg: " + subscriber_number + "  Conn: " + connection_number
				if len(line2) == 17: #If characters exceed 16 characters on display
					line2 = "Reg: " + subscriber_number + " Conn: " + connection_number
				elif len(line2) > 17: #Even more space required
					print("Line 2 overflow error")
					line2 = "Reg " + subscriber_number + " Conn " + connection_number
				updateScreen(line1, line2) #Send update command to display
				time.sleep(10) #Sleep for 10 seconds, then start again
	else:
		print("Incorrect state reached.") #Should never reach an incorrect state
		exit(0)

ser.close()

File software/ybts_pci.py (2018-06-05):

#Import necessary libraries
import os
import pprint
import json
import random
import string
from flowroutnumbersandmessaging.flowrouternumbersandmessaging_client import FlowroutenumbersandmessagingClient as flclient

#Import secret keys from the os and print error messages if they do not exist
if 'FR_ACCESS_KEY' in os.environ:
	username = os.environ.get('FR_ACCESS_KEY')
	print('Access Key acquired.')
else:
	print('ERROR: No Access key in the OS environment')

if 'FR_SECRET_KEY' in os.environ:
	password = os.environ.get('FR_SECRET_KEY')
	print('Secret key acquired.')
else:
	print('ERROR: No Secret key in the OS Environment')

test_mobile_number = "19017670182" #Create main test number (of the owner) for testing SMS/MMS and handling error messages from the system

client = flclient(username, password) #Instantiate flowroute client
numbers_cont = client.numbers #Create numbers controller
routes_controller = client.routes #Create routes controller
messages_controller = client.messages #Create messaging controller

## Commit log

2017-09-04 Added antenna folder
2017-09-04 Added models (pictures) for uplink antenna
2017-09-11 Added simulation files
    Using 4nec2 simulation software, added .nec files to reproduce
    simulation if required and added images of properties in different
    environements, radiation pattern diagrams in 2d/3d in different
    resolutions, and 3d images of the antenna structure itself
2017-09-21 Added electronic circuit diagram
    Still need to add balun and specific power rating for the Satellite
    modem power adapter
2017-10-22 Updated scripts
    Added how to get started on ubuntu, added more configuration options
    into setup.sh, and fixed start.sh to get going on multiple threads
    (still needs fixing with screen)
2017-10-26 Added antenna 3d models and images
    [antenna_assem.SLDASM, antenna_assem.SLDDRW, gndplane_segment.SLDASM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]
2017-10-31 Potential housing 3d models added (from online)
    [bladerf+daughterboard_base.stl, bladerf+daughterboard_lid.stl]
2017-11-12 Added powerpoint
    Explains basic working of the product
2017-11-12 Reorganized folders and documents
    [antenna_assem.SLDASM, antenna_assem.SLDDRW, bladerf+daughterboard_base.stl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]
2017-11-15 Update models with correct material
    [midsection.SLDASM, pvc_17mm_cap.SLDPRT, pvc_17mm_straight79mm.SLDPRT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]
2018-06-12 Added prototype product briefs
2018-06-12 Added temperature testing scripts, web server scripts, and logs from test
2018-06-21 Changes to flowroute scripts
2018-06-21 Added logs from testing
    [yate-cdr.csv]
2018-06-21 Fixed autoassignment and added more network logs
    [yate-cdr.csv]
